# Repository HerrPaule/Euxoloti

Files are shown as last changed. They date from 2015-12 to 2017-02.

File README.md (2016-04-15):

# Euxoloti
Euxoloti is a project to use the great Axoloti core in the world of Eurorack. 

The project is fully open and released under CC-BY-SA-NC

Further deatils about functions and order, check http://irieelectronics.de/euxoloti
and the Axoloti Forum: http://community.axoloti.com/t/euxoloti-for-axoloti-eurorack-module/

A great detailed build step by step instruction by FMA from the Axoloti Forum (work in progress): https://docs.google.com/document/d/1Rx9O_k-dUJQDzONVk0AzewmyFckbQyXHiNsPy8fmUj8/edit

AXOLOTI: http://axoloti.be
<br>
Book about the Axoloti: https://leanpub.com/getting-started-with-axoloti

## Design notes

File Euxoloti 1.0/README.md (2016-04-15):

##### Changelog

####### Core PCB Version 1.1:
- error correction 
- some components are rearranged or deleted
- Analog ground for ADCs, POTs and AUDIO
- better heat management for Vreg (PCB can be used as heat sink or a heatsink for TO-220)
- CS pins from ADCs are connected to other Axo pinouts
- detailed labels for pin outs and used pins.
- connections to connect upcoming "GAT8" and "USB2MCV" extensions. 
- optional use of lin/rin pins for audio directly or normalize the Eurorack signal by a big audio jack to the audio input header behind Axo's audio in jack. so you can use mics etc. like normal with Axoloti) 

####### Control PCB Version 1.1:
- larger PCB height to connect the bottom Thonkiconn jack row directly to the PCB
- single ground pins (AGND/DGND) for CV IN/GATE, POT, AUDIO I/O and pushbutton/led GND
- footprint is for LP4OA1PBCTG or D6 switches
- LEDs are now connected to PWM outputs
- Pot orientation is compatible to d-shaft type pots

####### New:
PCB Panels for Control, GAT8 and USB2MCV

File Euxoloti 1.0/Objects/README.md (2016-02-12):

### Euxoloti Objects
- LED + Button Object: It reads the pushbutton states and let you turn on/off the LEDs. 
- Gate Object: It's reads and outputs the value of the gate cv in jacks. (Only on/off)

###Installation:
1. go to axoloti's object folder Mac: ./Applications/Axoloti.app/Contents/Java/objects/
2. create a new dir and name it "euxoloti"
3. copy the "button-led.axo" & "gate.axo"
4. start axaloti app and it will update its object list (no error at axoloti console)
5. the editor should list now euxoloti

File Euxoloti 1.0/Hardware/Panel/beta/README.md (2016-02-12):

The actually used panel is a printed [3mm Alu-Dibond plate](https://de.whitewall.com/fotolabor/alu-dibond/direktdruck-aluminium?linkId=TopNavigation) comes from white wall.
- Width: 101mm
- Height: 128mm

Drill positions are marked by Crosses.

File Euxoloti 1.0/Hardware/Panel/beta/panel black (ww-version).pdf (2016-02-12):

GATE IN | AUDIO
OUT R | OUT L

CV IN

1 | 2 | 3 | 4
5 | 6 | 7 | 8

1

2

IN R | IN L
1 | 2 | 3 | 4
P1 | P2 | P3 | P4
P5 | P6 | P7 | P8
BUTTON
- | + - | + - | + - | +
- | + - | + - | + - | +

## EUXOLOTI

### irie electronics

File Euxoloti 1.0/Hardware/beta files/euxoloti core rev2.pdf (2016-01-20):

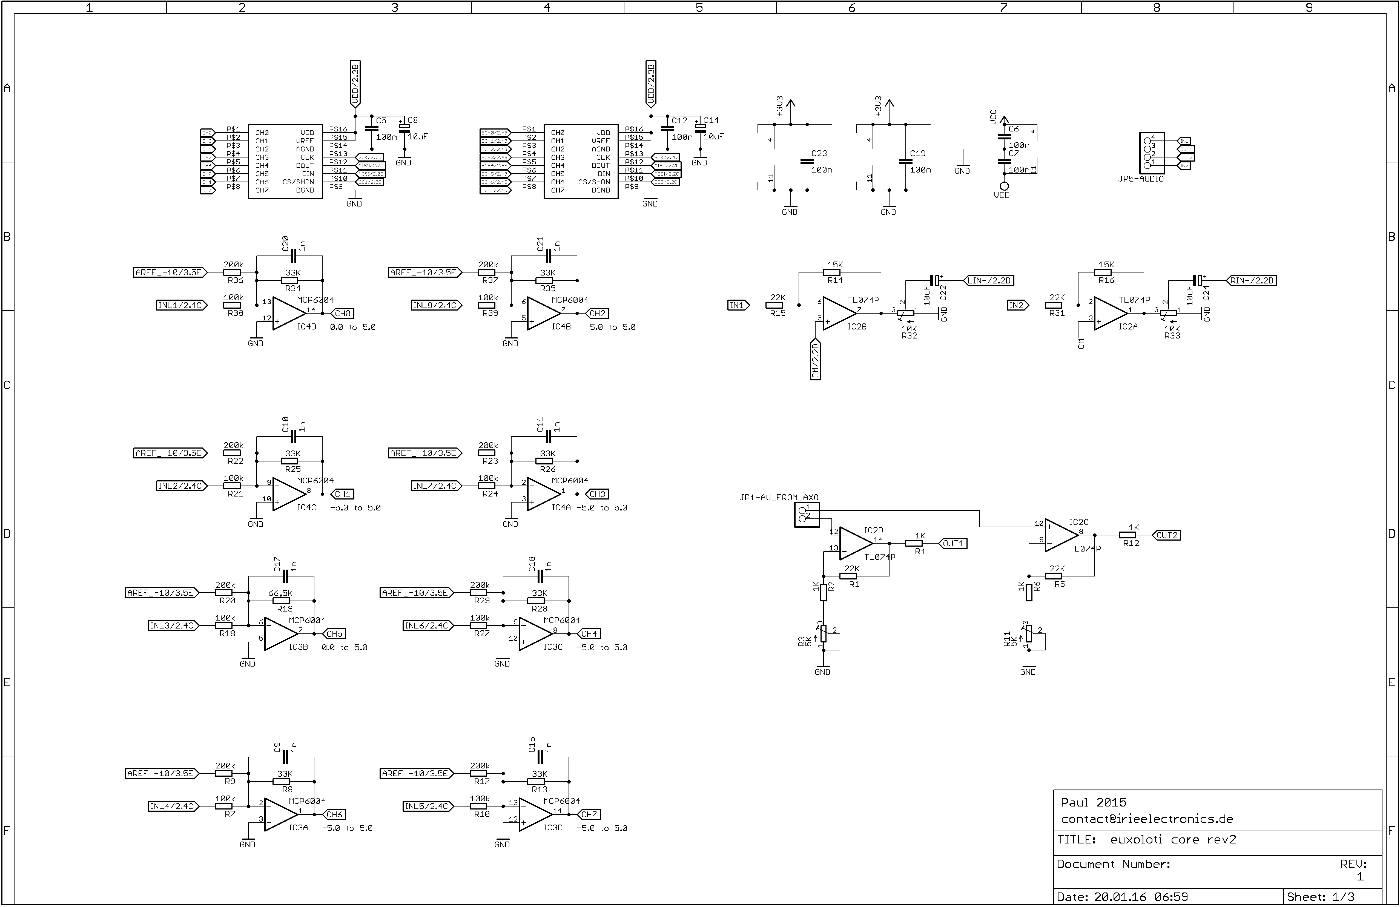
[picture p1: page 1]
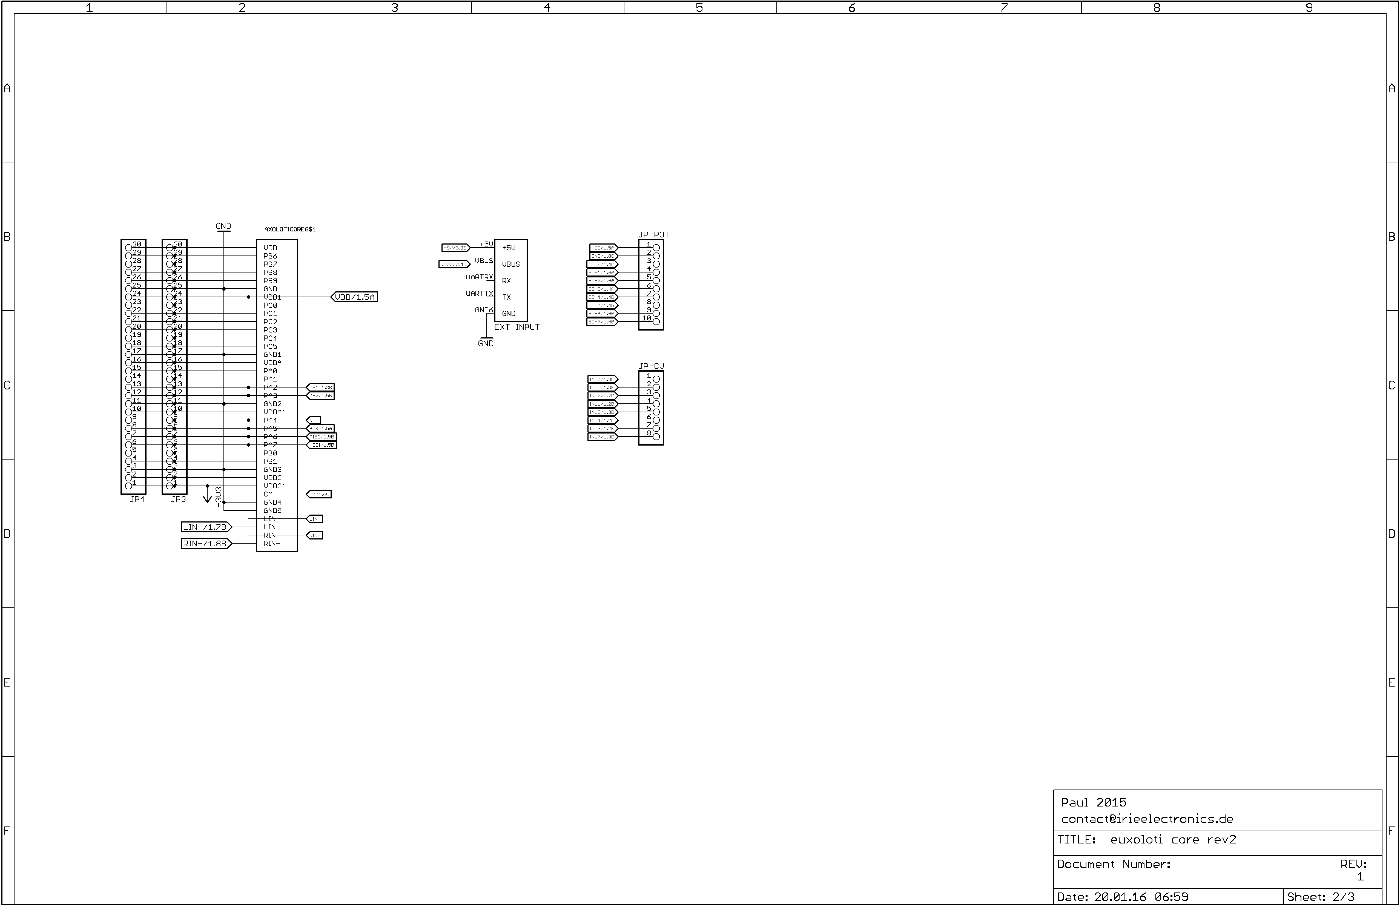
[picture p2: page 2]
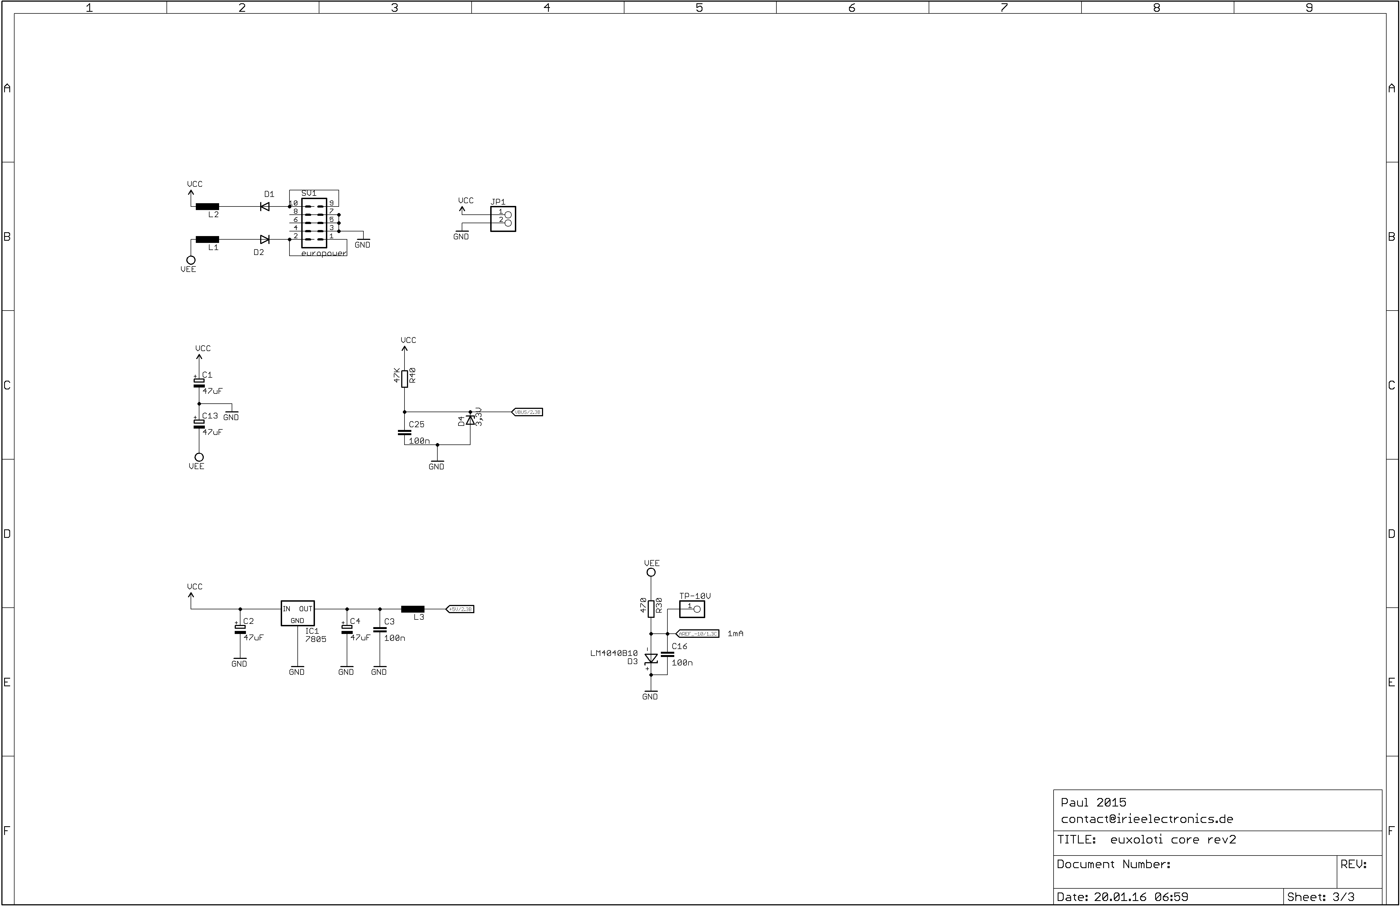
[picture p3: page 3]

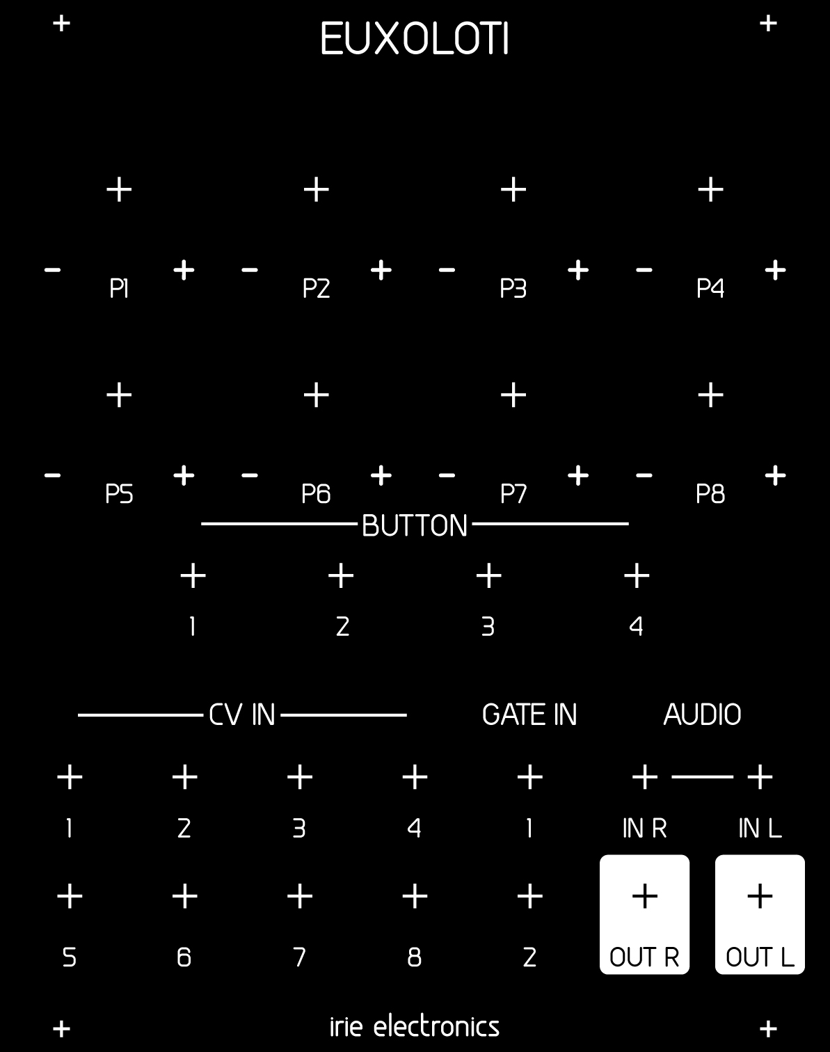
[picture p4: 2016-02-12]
Euxoloti 1.0/Hardware/Panel/beta/panel black (ww-version).jpg

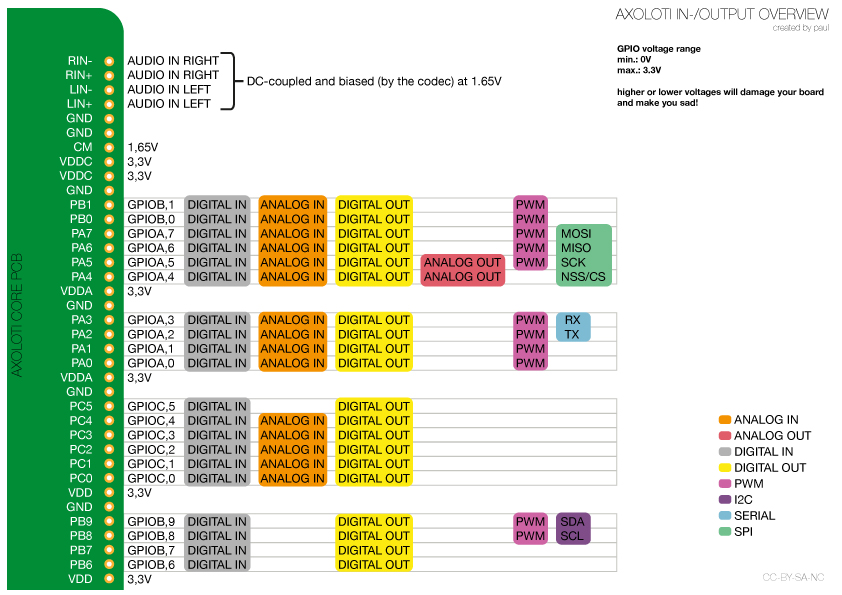
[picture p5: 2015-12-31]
AXOLOTI PINOUT OVERVIEW/axoloti-gpio-io-v2.jpg

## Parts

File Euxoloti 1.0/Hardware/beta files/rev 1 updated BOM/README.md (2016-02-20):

## Please, also add following parts to your shopping cart:
- Axoloti Pinout: 1x37 pin male header row
- Axoloti Power: 1x5 pin male header row
- Axo-Euxo Connection: 36pin female header row  
- Axo-Euxo Power: 1x5 pin female header row 

#### Mouser carts:
- [BOM Core PCB](http://www.mouser.com/ProjectManager/ProjectDetail.aspx?AccessID=0fd288abd9)
- [BOM Control PCB](http://www.mouser.com/ProjectManager/ProjectDetail.aspx?AccessID=da0791eec8)
- [Axo-Euxo Header](http://www.mouser.com/ProjectManager/ProjectDetail.aspx?AccessID=f23408b07c)

#### special note about pots
toneburst@axoloti forum (euxoloti thread):
Also, just noticed the pots are in different orientations, which means I can't use the Panasonic pots, or the pointers on the knobs will point in the wrong directions.

Might have been a good idea to make a note of that in the BOM or, preferably put all the pots the same way round, so people can use D-Shaft pots if they want to. It's not a dense board, wouldn't be difficult to orient them all like the top row, I don't think.

from: http://community.axoloti.com/t/euxoloti-for-axoloti-eurorack-module/100/102?u=paul

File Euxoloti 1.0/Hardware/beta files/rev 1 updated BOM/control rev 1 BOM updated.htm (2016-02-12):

Euxoloti Control PCB REV 1.0 updated BOM
Qty | Parts | Value | Description | Package | Mouser | Alternative
4 | R1, R3, R5, R7 | 68R | Resistor, 5% |  | 71-CCF0768R0JKE36
2 | R11, R12 | 10K | Resistor, 5% |  | 660-MF1/4LCT52R103J
2 | R9, R10 | 100K | Resistor, 5% |  | 660-MF1/4LCT52R104J
2 | T1, T2 | 2N3904 | NPN Transistor | TO-92 | 512-2N3904TAR
4 | B1, B2, B3, B4 | Switch, On-mom, Green LED |  |  | 612-LP4OA1PBCTG | 612-LP4OA1PBCTR
1 | JP-POT | 1x10 male header, 2.54mm pitch | check core bom | 1X10
1 | JP1 | 1x30 male header, 2.54mm pitch | check core bom | 1X30
1 | JP3-AUDIO | 1x4 male header, 2.54mm pitch | check core bom | 1X04
1 | JP3-CV | 1x8 male header, 2.54mm pitch | check core bom | 1X08
8 | POT1, POT2, POT3, POT4, POT5, POT6, POT7, POT8 | 10K | Alpha, 10k linear pot, vertical | 9mm |  | https://www.thonk.co.uk/shop/alpha-9mm-pots/
14 | A-IN1, A-IN2, A-OUT1, A-OUT2, CV1, CV2, CV3, CV4, CV5, CV6, CV7, CV8, G-IN1, G-IN2 | THONKICONN |  |  |  | https://www.thonk.co.uk/shop/3-5mm-jacks/
1 |  | M3, 10mm | Spacer female | 10mm | 855-R30-1001002
1 |  | M3, 6mm | Screw | 6mm | 534-9191-4

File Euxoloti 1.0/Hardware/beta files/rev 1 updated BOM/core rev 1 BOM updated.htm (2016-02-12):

Euxoloti Core PCB REV 1.0 updated BOM
Qty | Parts | Value | Description | specs | Package | Mouser
3 | L1, L2, L3 |  | Ferrite Bead |  |  | 81-BL01RN1A1D2B
1 | R30 | 470R |  |  |  | 660-MF1/4DC4700F
4 | R2, R4, R6, R12 | 1K | Resistor, 1% |  |  | 660-MS1/4DCT52R1001
2 | R14, R16 | 15K | Resistor, 1% |  |  | 660-MFS1/4DCT52R1502
4 | R1, R5, R15, R31 | 22K | Resistor, 1% |  |  | 660-MF1/4DC2202F
7 | R8, R13, R25, R26, R28, R34, R35 | 33K | Resistor, 1% |  |  | 660-MF1/4DC3302F
1 | R40 | 47K | Resistor, 1% |  |  | 660-MF1/4LCT52R473J
1 | R19 | 66,5K | Resistor, 1% |  |  | 660-MF1/4DC6652F
8 | R7, R10, R18, R21, R24, R27, R38, R39 | 100k | Resistor, 1% |  |  | 660-MF1/4D52R1003F
8 | R9, R17, R20, R22, R23, R29, R36, R37 | 200k | Resistor, 1% |  |  | 660-MF1/4DC2003F
2 | R3, R11 | 5K | Trimmer |  |  | 652-3299P-1-502LF
2 | R32, R33 | 10K | Trimmer |  |  | 652-3299P-1-103LF
8 | C9, C10, C11, C15, C17, C18, C20, C21 | 1n | Capacitor, ceramic | >= 16V, <= 2% | Pitch: 5mm | 80-C322C102F5G
9 | C3, C5, C6, C7, C12, C16, C19, C23, C25 | 100n | Capacitor, ceramic | >= 16V | Pitch: 2,5mm | 75-1C10Z5U104M050B
4 | C8, C14, C22, C24 | 10uF | Capacitor, electrolytic | >= 6V | Pitch: 1,8mm; Dia.: 4mm | 667-ECE-A1CKS100
4 | C1, C2, C4, C13 | 47uF | Capacitor, electrolytic | >= 16V | Pitch: 2mm; Dia.: 5mm | 667-ECE-A1CKA470
2 | D1, D2 | 1N5819 | Diode |  | DO35 | 512-1N5819
1 | D4 | 3,3V, 500mW | Zener Diode |  | DO35 | 771-BZX79-C3V3-T/R
1 | D3 | LM4040 10V | Ref Diode | A, B or C grade | TO-92 | 926-LM4040AIZ100NOPB
1 | IC1 | 7805 | Voltage Regulator |  | TO-220 | 512-LM7805ACT
2 | IC5, IC6 | MCP3208 | ADC |  | DIL16 | 579-MCP3208CIP
2 | IC3, IC4 | MCP6004 | OP AMP |  | DIL14 | 579-MCP6004-I/P
1 | IC2 | TL074 | OP AMP |  | DIL14 | 595-TL074CN
1 | JP_POT |  | 1x10 female header, 2.54mm pitch |  | 1X10
2 | JP3, JP4 |  | 1x30 female header, 2.54mm pitch |  | 1X30
1 | JP5-AUDIO |  | 1x4 female header, 2.54mm pitch |  | 1X04
1 | JP-CV |  | 1x8 female header, 2.54mm pitch |  | 1X08
1 | SV1 |  | 2x10 male header, 2.54mm pitch |  | 2x10
 |  |  | IC Socket, DIL14 |  |  | 649-DILB14P-223TLF
3 |  |  | IC Socket, DIL16 |  |  | 649-DILB16P-223TLF
2
1 |  | M3, 10mm | Spacer female/male |  | 10mm | 855-R30-3001002
1 |  | M3, 6mm | Screw |  | 6mm | 534-9191-4
2 |  | 10cm | Cable to connect axoloti audio out
1 |  |  | 1x2 femal crimp contact |  | 1x2
1 | AXOLOTICORE | AXOLOTI CORE |  |  |  |  | http://www.axoloti.com/product/axoloti-core/
1 | Eurorack power cable
 | HINT:
2 |  |  | only for core | (cut to fit) | 1x36 female header, 2.54mm pitch |  |  | 517-929974-01-36-RK
2 |  |  | core & control pcb | (cut to fit) | 1x36 male header, 2.54mm pitch |  |  | 649-68000-436HLF

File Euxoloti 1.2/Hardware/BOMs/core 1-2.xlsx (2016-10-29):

Qty | Value | Parts | Description | Package | DIGI Key | MOUSER
3 |  | L1, L2, L3 | EMI Filter Bead |  | 490-10997-ND | 623-2743002112LF
1 | 470R | R39 | Resistor, 1% |  | RNF14FTD470RCT-ND
2 | 1K | R19, R20 | Resistor, 1%
4 | 3,3K | R13, R14, R35, R36 | Resistor, 1%
2 | 10K | R41, R42 | Resistor, 1%
4 | 22K | R17, R18, R29, R30 | Resistor, 1%
7 | 33K | R3, R4, R11, R12, R24, R33, R34 | Resistor, 1%
1 | 66,5K | R23 | Resistor, 1%
9 | 100k | R1, R2, R9, R10, R21, R22, R31, R32, R40 | Resistor, 1%
8 | 200k | R5, R6, R15, R16, R25, R26, R37, R38 | Resistor, 1%
1 | 10K | RN1 | Resistor Networks, Star Connection | 4x10k (5legs)
2 | 5k | R7, R8 | Trimmers Pots, Precision, horizontal, triangle legs |  |  | 652-3296P-1-502LF
2 | 10K | R27, R28 | Trimmers Pots, Precision, horizontal, triangle legs |  |  | 652-3296P-1-103LF
8 | 1n | C1, C2, C3, C4, C5, C6, C9, C10 | Capacitor, film; <=2.5% | pitch: 2,5mm or 5mm |  | 505-FKP21000/100/2.5
8 | 100n | C11, C12, C13, C14, C17, C20, C21, C22 | Capacitor, ceramic | pitch: 2,5 | 445-5312-ND
1 | 330n | C15 | Capacitor, ceramic | pitch: 2,5
2 | 10uF | C7, C8 | Capacitor, electrolytic | pitch: 1,8mm; Dia 4mm
2 | 47uF | C18, C19 | Capacitor, electrolytic | pitch: 2mm; Dia: 5mm | 493-11510-1-ND
4 | 1N4001 | D2, D4, D5, D6 | Diode | DO35
1 | 3,3V | D3 | Zener diode | DO35
1 | LM4040A10 | D1 | LM4040 Shunt Vref; A, B or C grade | TO-92 | LM4040AIZ-10.0/NOPB-ND | 926-LM4040AIZ100NOPB
1 | 7805 | VREG | Vreg | TO-220 | LM7805ACT-ND | LM7805ACT
2 | MCP6004 | IC1, IC3 | Op amp | DIL14 | MCP6004-I/P-ND
1 | TL074P | IC2 | Op amp | DIL14
1 | MAPPLE_MINI_REV2 | IC4 | Maple Mini Clone | STM32F103RCBT6 | http://www.ebay.de/itm/Mini-USB-STM32F103RCBT6-ARM-Cortex-M3-leaflabs-Leaf-Maple-Mini-Module-F-Arduino-/182198487350
1 | Axoloti Core | Axoloti Core |  |  | http://www.axoloti.com/
2 | female | Maple Mini (IC4) | PIN HEADER | 1X20; pitch: 2,54mm; low profile
1 | female | JP-MM | PIN HEADER | 1X20; pitch: 2,54mm | 929850E-01-20-ND
1 | female | JP-AG | PIN HEADER | 1X7; pitch: 2,54mm | 929974E-01-36-ND
1 | female | JP-MGVG | PIN HEADER | 2X5; pitch: 2,54mm | to use some 1x36 is cheaper
1 | female | JP-BLCG | PIN HEADER | 2X11; pitch: 2,54mm | to use some 1x36 is cheaper
1 | female | AXO_CORE | PIN HEADER | 1x37; pitch: 2,54mm | to use some 1x36 is cheaper
1 | female | AXO_CORE (Power, MIDI Section) | PIN HEADER | 1x5; pitch: 2,54mm | to use some 1x36 is cheaper
1 | male | EURORACK-POWER | PIN HEADER | 2X5; pitch: 2,54mm
3 |  | IC Socket |  | DIL14
1 | fe-/male | Nylon Stand off |  | 10mm; M3 | 36-25501-ND
1 | female | Nylon Stand off |  | 10mm; M3 | 36-25510-ND
1 |  | Heatsink |  | TO-220 | HS115-ND
1 |  | Thermal pad |  | TO-220 | BER167-ND
85
For Axoloti Core
1 | male | AXO_CORE |  | 1x37
1 | male | AXO_CORE (Power, MIDI Section) |  | 1x5
red marked parts not included in part kits!

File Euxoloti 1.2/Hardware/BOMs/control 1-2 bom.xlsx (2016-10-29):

Qty | Value | Parts | Description | Package | DIGI Key | MOUSER
2 | 51R | R7, R8 | Resistor, 1%
4 | 68R | R1, R2, R13, R19 | Resistor, 1%
1 | 220R | R10 | Resistor, 5%
5 | 10K | R4, R6, R11, R14, R20 | Resistor, 1%
4 | 100K | R3, R5, R9, R12 | Resistor, 1%
1 | 100n | C1 | Capacitor, ceramic | pitch: 2,5mm
1 | 1N4148 | D1 | Diode | DO35
4 | 2N3904 | N1, N2, N3, N4 | NPN Transistor | TO92
1 | 6N137 | IC2 | Opto coupler | DIL08
16 | THONKICONN | A-IN1, A-IN2, A-OUT1, A-OUT2, CV1, CV2, CV3, CV4, CV5, CV6, CV7, CV8, G-IN1, G-IN2, G-IN3, G-IN4 | 3.5mm socket for Eurorack modular synths |  | https://www.thonk.co.uk/shop/3-5mm-jacks/
1 | USB-LUMBERG | USB-B_JACK |  | USB-B
2 | MIDIJACK | MIDIIN, MIDIOUT |  | SD-50BV | CP-3150-ND
1 | male | USB-AXO | pitch 2,54mm | 1x5 | WM4203-ND
1 | female |  | pitch 2,54mm | 1x5 | WM2003-ND
5 |  | crimp |  | female header, crimp contact | WM1114-ND
8 | 10K, linear | POT1, POT2, POT3, POT4, POT5, POT6, POT7, POT8 | 9mm vertical snap-in pot, Alpha / Panasonic style
4 | LP4OA1PBCTG | B1, B2, B3, B4 |  | LP4OA1PBCT | EG4650-ND | 612-LP4OA1PBCTR
1 | male | JP-MM1.1 | PIN HEADER | 1X03
1 | male | JP-AG | PIN HEADER | 1X07
1 | male | JP-MM1.2 | PIN HEADER | 1X09
1 | male | JP-BLC | PIN HEADER | 2X11
1 | male | JP-MGVG | PIN HEADER | 2X05
1 |  |  | 1x5 | 1x5 female header, 2,54mm pitch
1
1 |  |  | USB micro to usb A
1 |  |  | IC Socket | DIL8
70
red marked parts not included in part kits!

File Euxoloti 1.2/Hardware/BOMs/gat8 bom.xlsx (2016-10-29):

Qty | Value | Parts | Description | Device | MOUSER
1 |  | L1 | EMI Filter Bead |  | 623-2743002112LF
8 | 2,2K | R25, R26, R27, R28, R29,R30,R31,R32 | Resistor, 1% | 1206
8 | 4,7K | R5, R6, R7, R8, R9, R10, R11, R12 | Resistor, 1% | 1206
8 | 10K | R1, R2, R3, R4, R21, R22, R23, R24 | Resistor, 1% | 1206
2 | 100nF | C1,C6 | Capacitor, ceramic | 1206
1 | 330n | C3 | Capacitor, ceramic | 1206
1 | 47uF | C2 | Capacitor, electrolytic | pitch: 2mm; Dia: 5mm
1 | 1N4001 | D1 | Diode | 1N4004
8 | 2N3904 | T1, T2, T3, T4, T5, T6, T7, T8 | NPN TRANSISTOR | 2N3904
1 | 78l03 | IC2 | VOLTAGE REGULATOR | TO92
1 | 74LS595N | IC1 | 8-bit SHIFT REGISTER | 74HC595
8 | LED | LED1, LED2, LED3, LED4, LED5, LED6, LED7, LED8 |  | flat LED
1 |  | MASTER | PIN HEADER | PINHD-1X5_2.54
1 | male | EURORACK-POWER | PIN HEADER | 2X5; pitch: 2,54mm
1 | DIP socket |  |  | DIL16
8 | PJ302M | OUT1, OUT2, OUT3, OUT4, OUT5, OUT6, OUT7, OUT8 |  | PJ302M
59
red marked parts not included in part kits!

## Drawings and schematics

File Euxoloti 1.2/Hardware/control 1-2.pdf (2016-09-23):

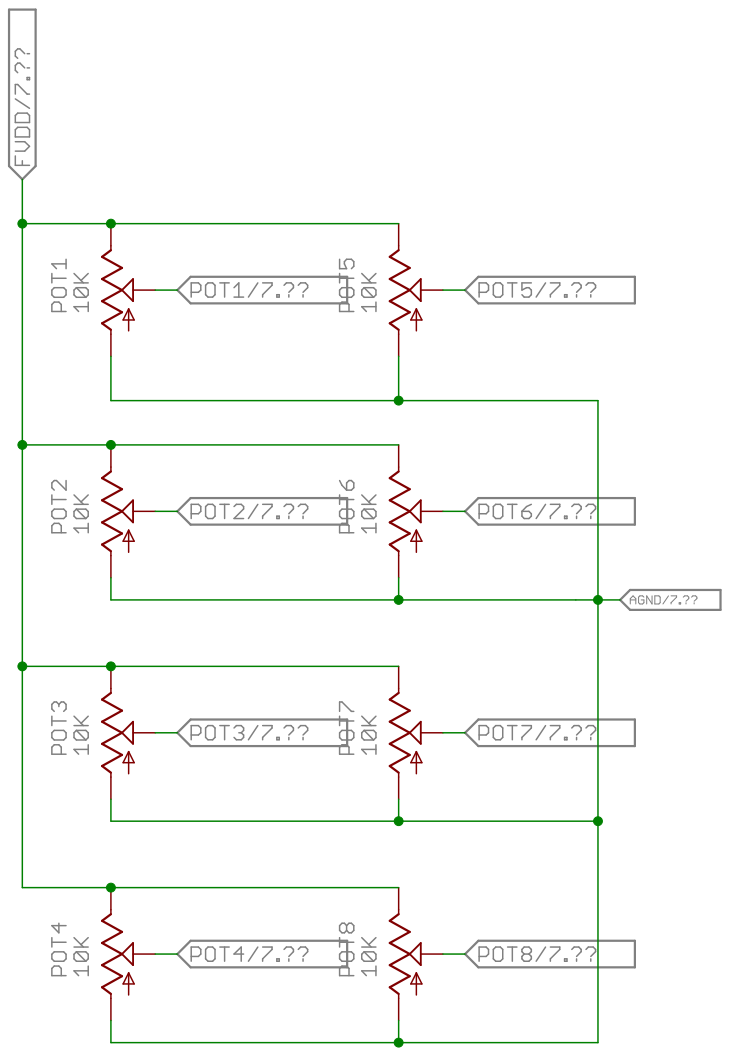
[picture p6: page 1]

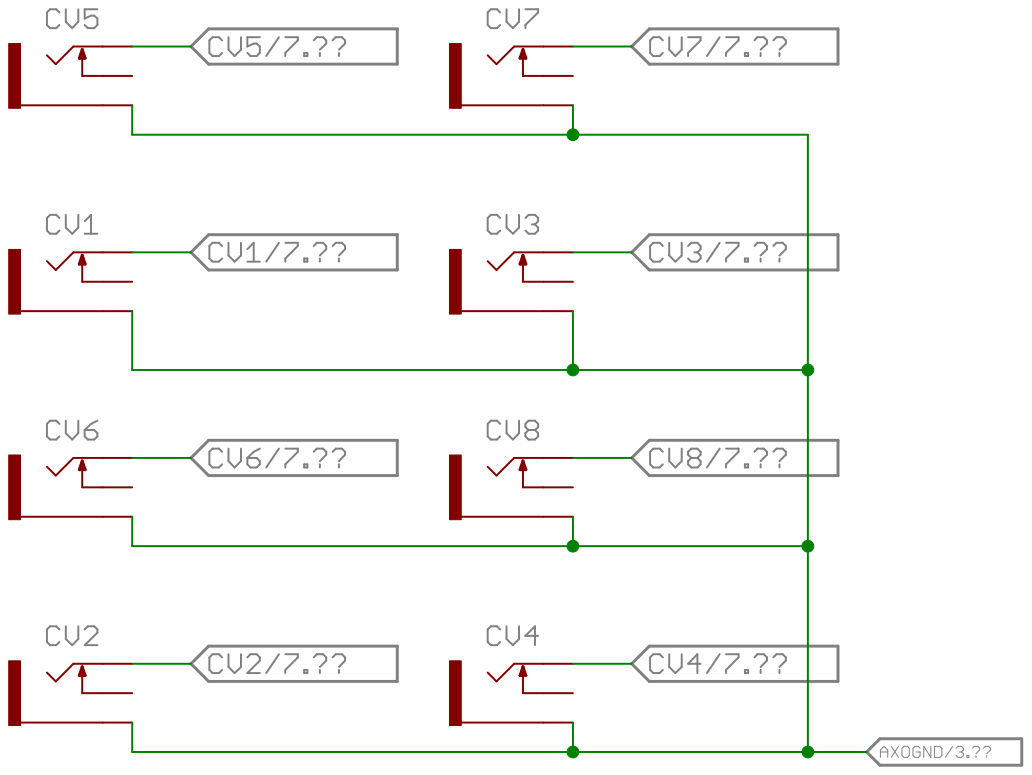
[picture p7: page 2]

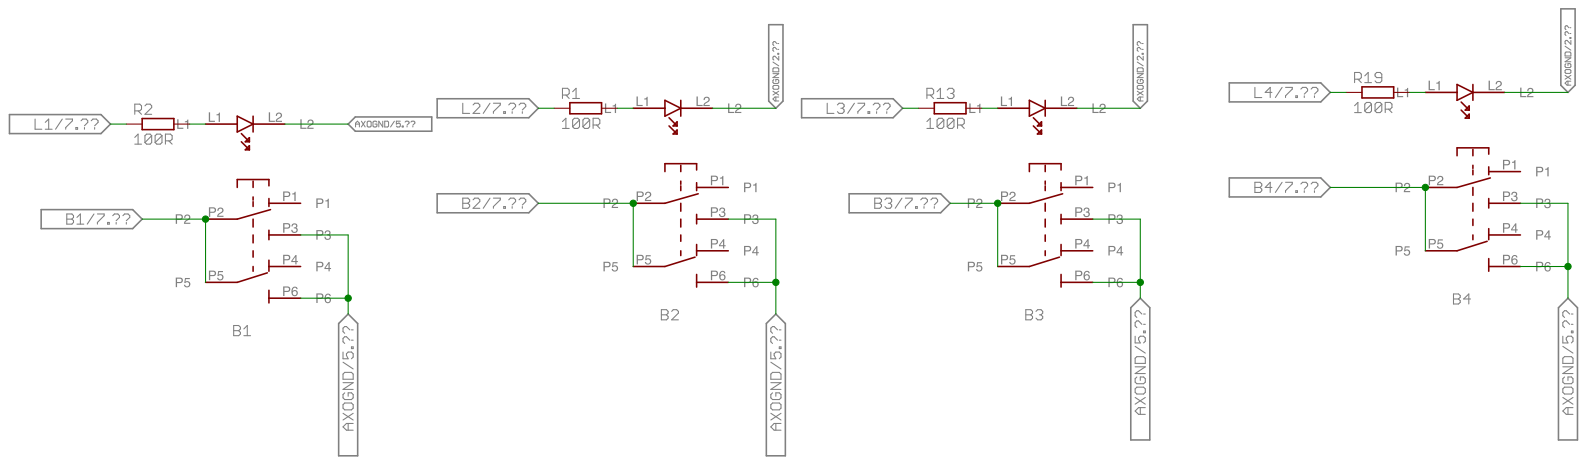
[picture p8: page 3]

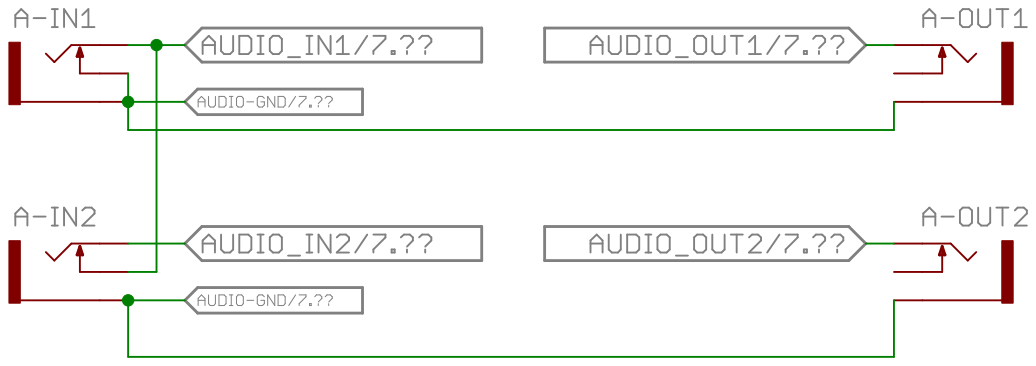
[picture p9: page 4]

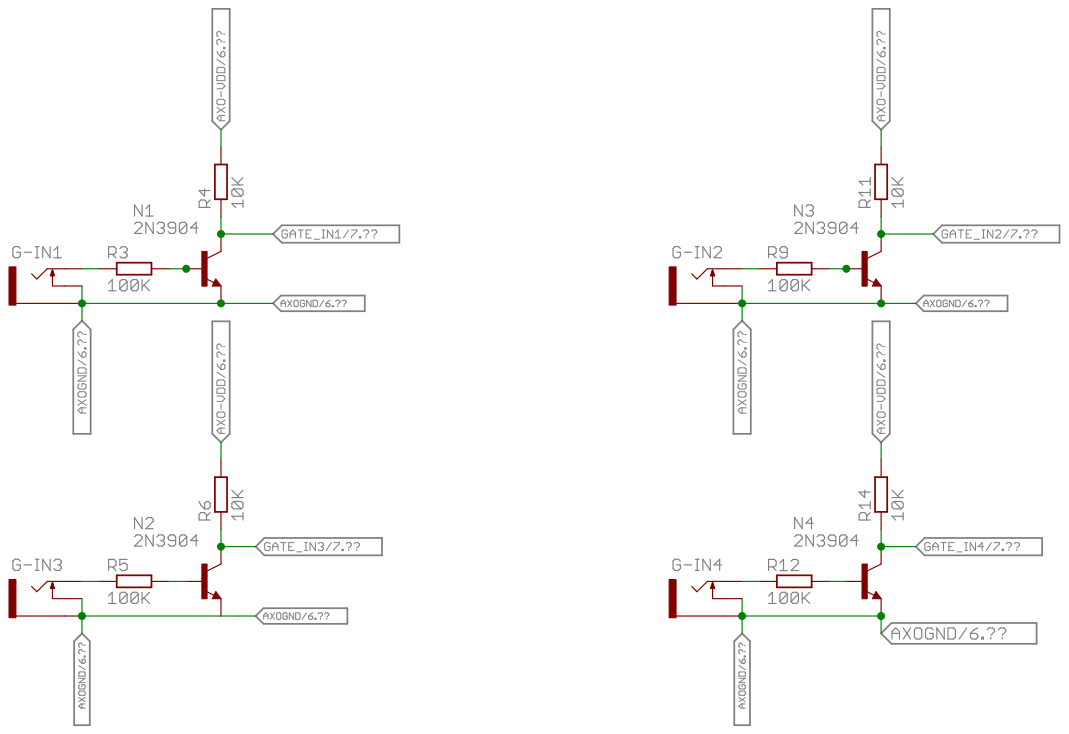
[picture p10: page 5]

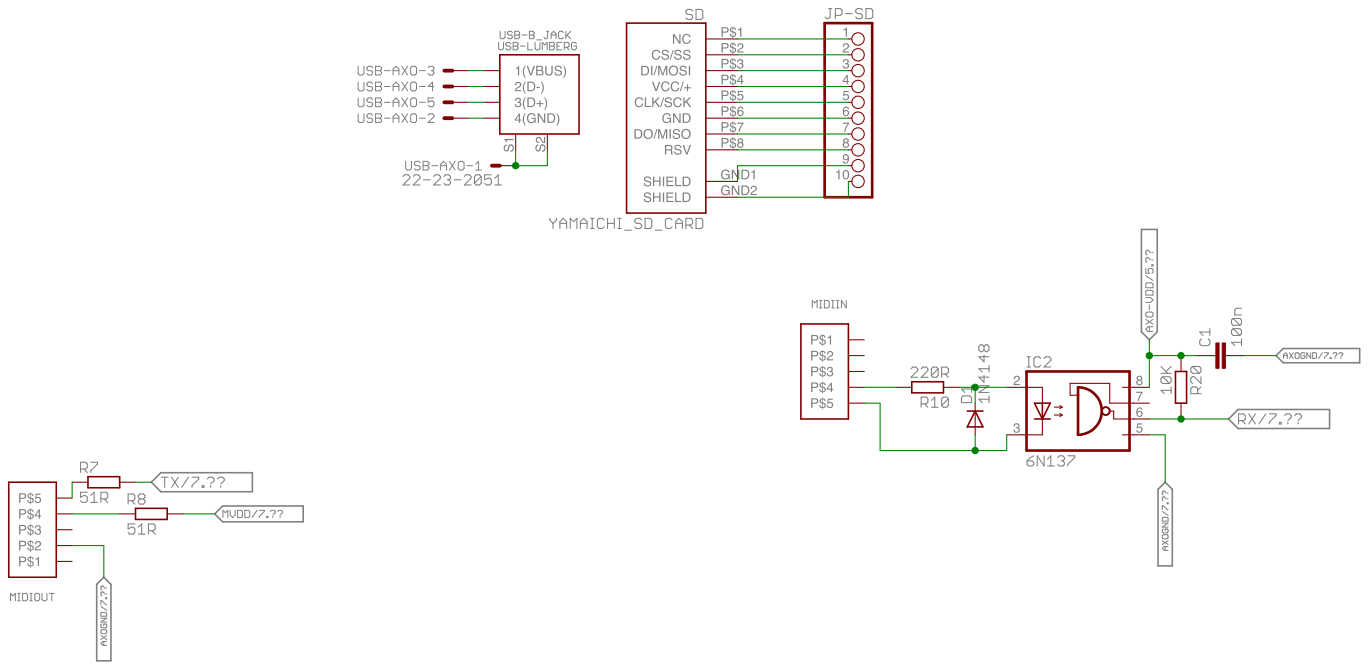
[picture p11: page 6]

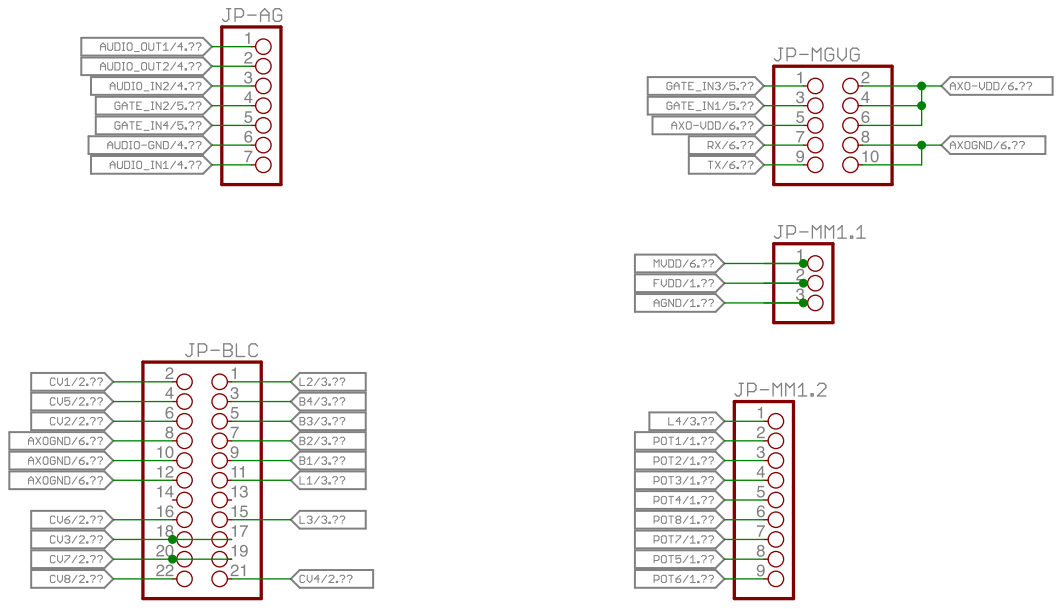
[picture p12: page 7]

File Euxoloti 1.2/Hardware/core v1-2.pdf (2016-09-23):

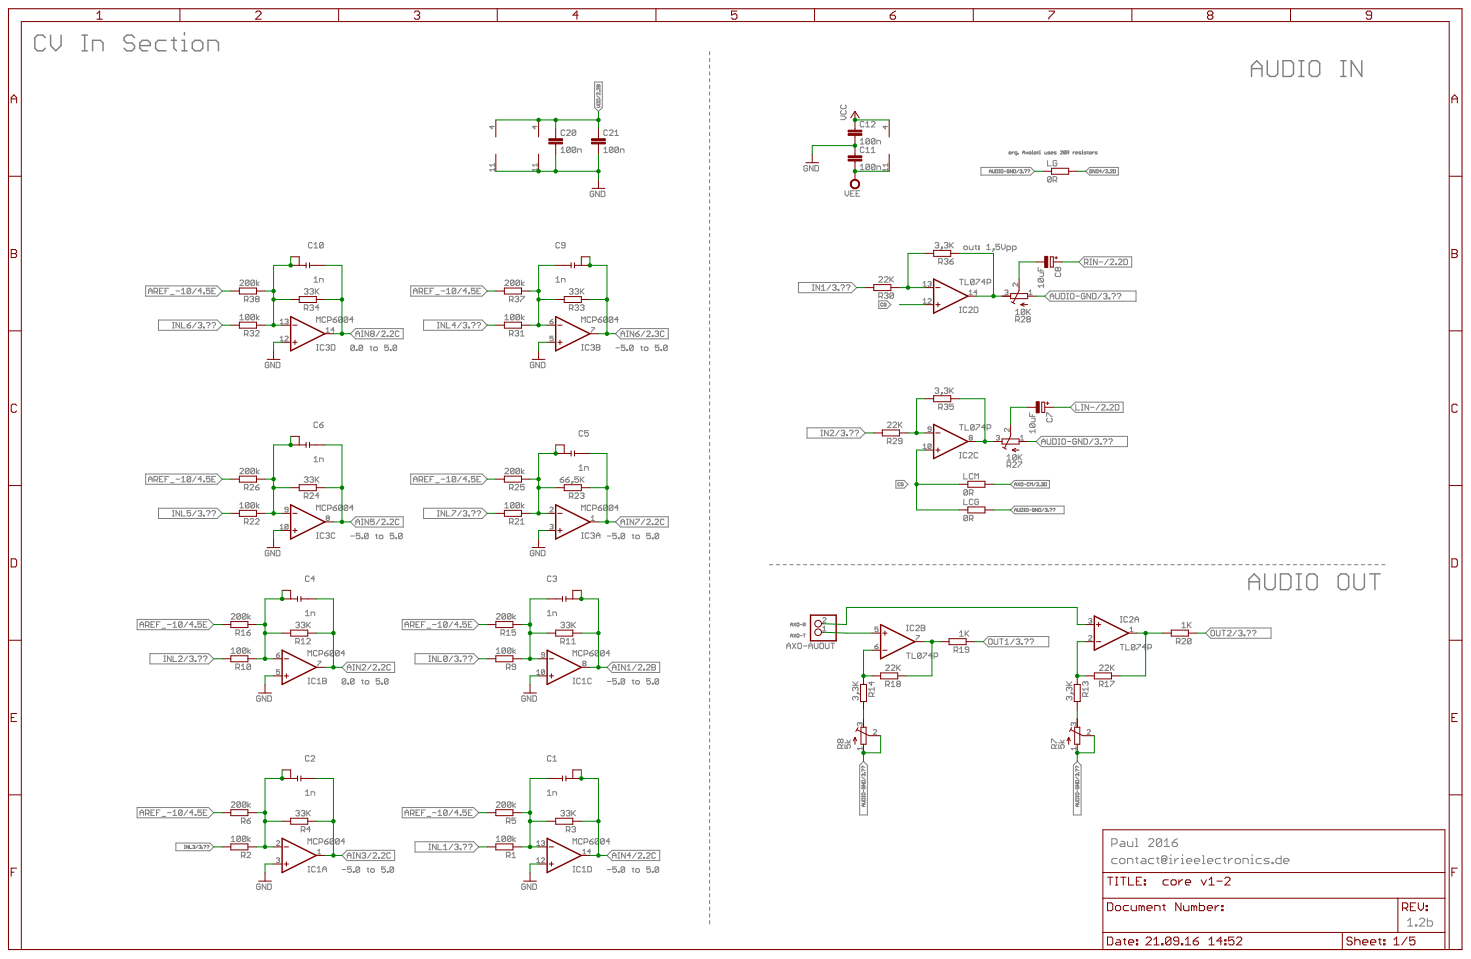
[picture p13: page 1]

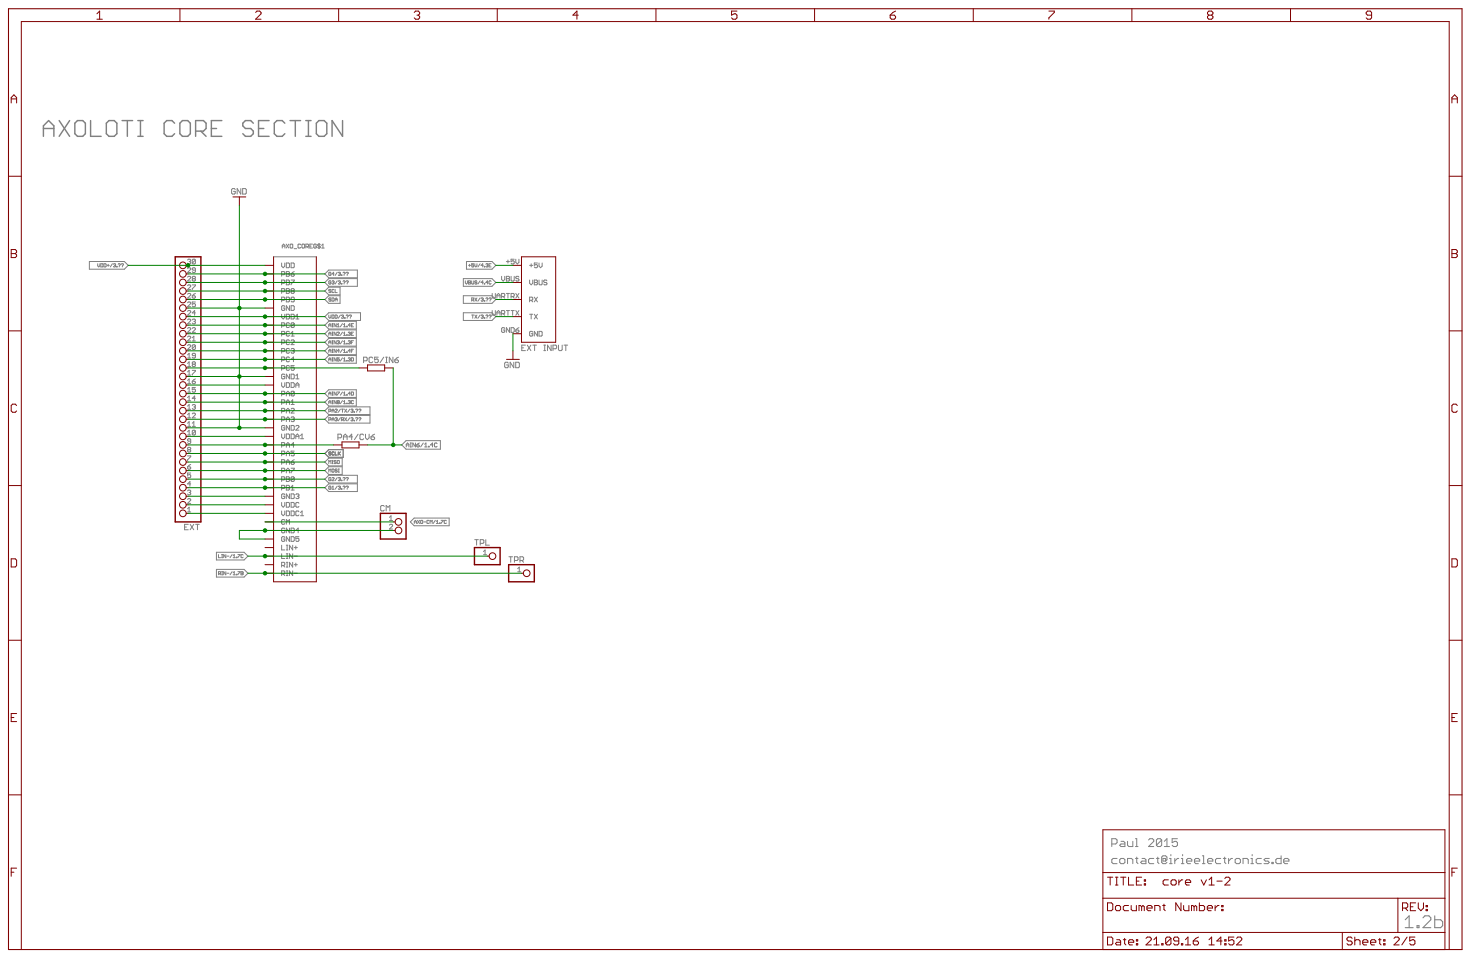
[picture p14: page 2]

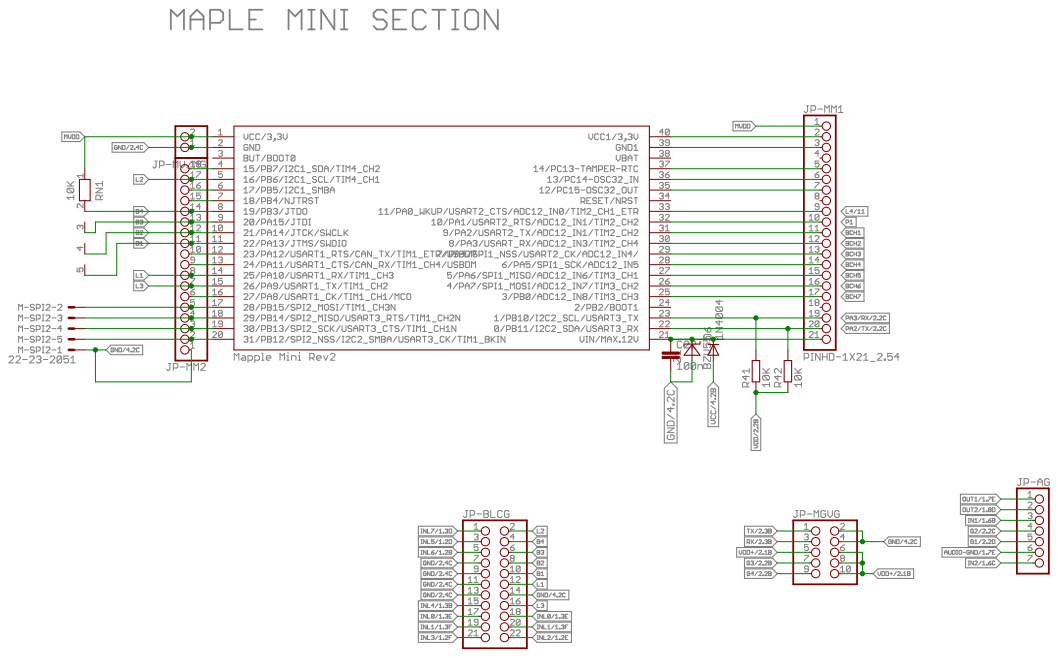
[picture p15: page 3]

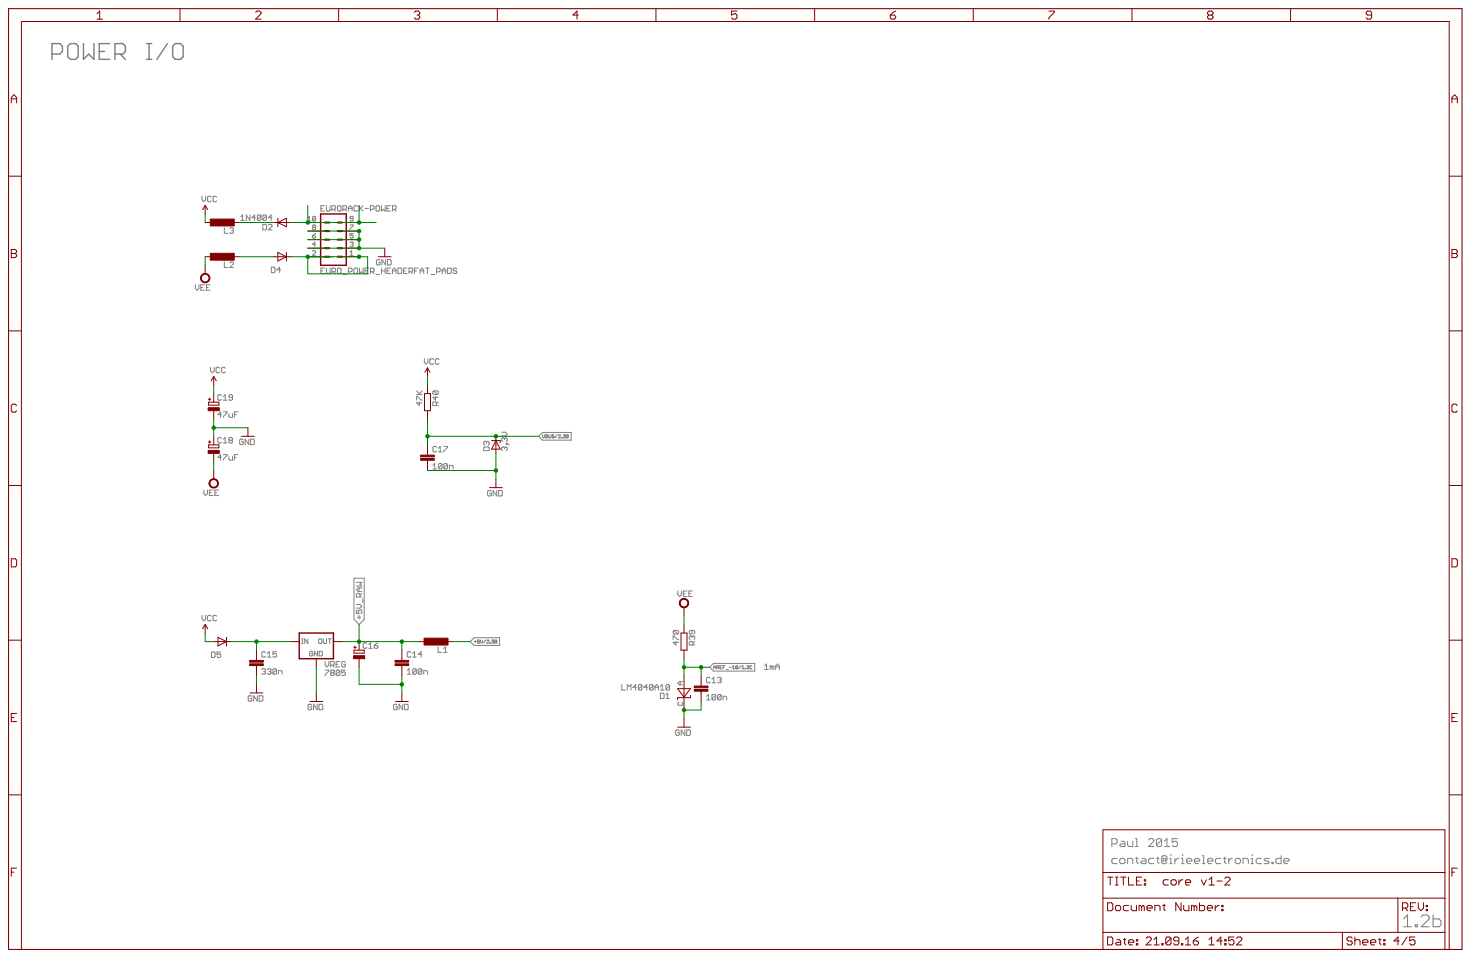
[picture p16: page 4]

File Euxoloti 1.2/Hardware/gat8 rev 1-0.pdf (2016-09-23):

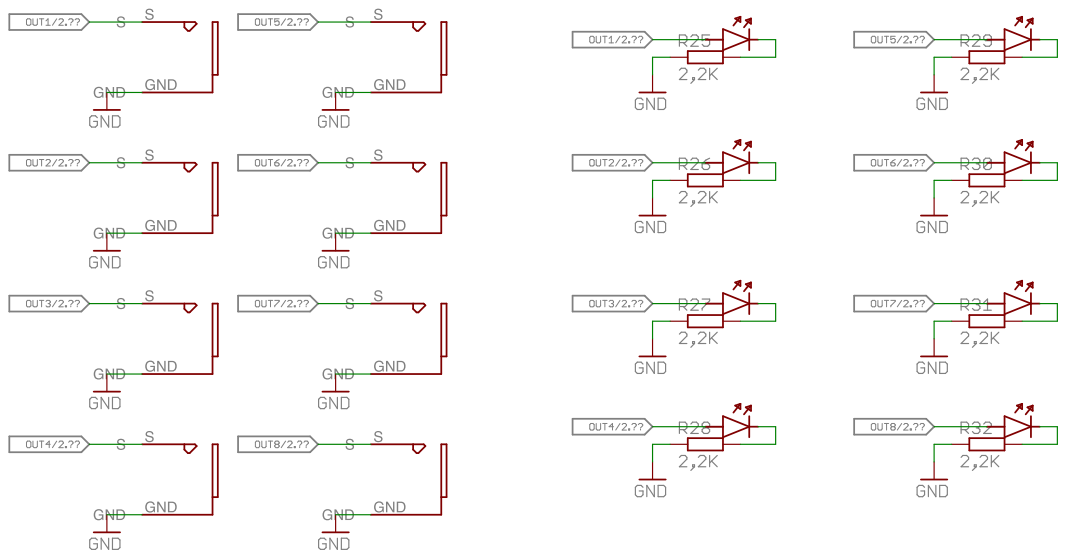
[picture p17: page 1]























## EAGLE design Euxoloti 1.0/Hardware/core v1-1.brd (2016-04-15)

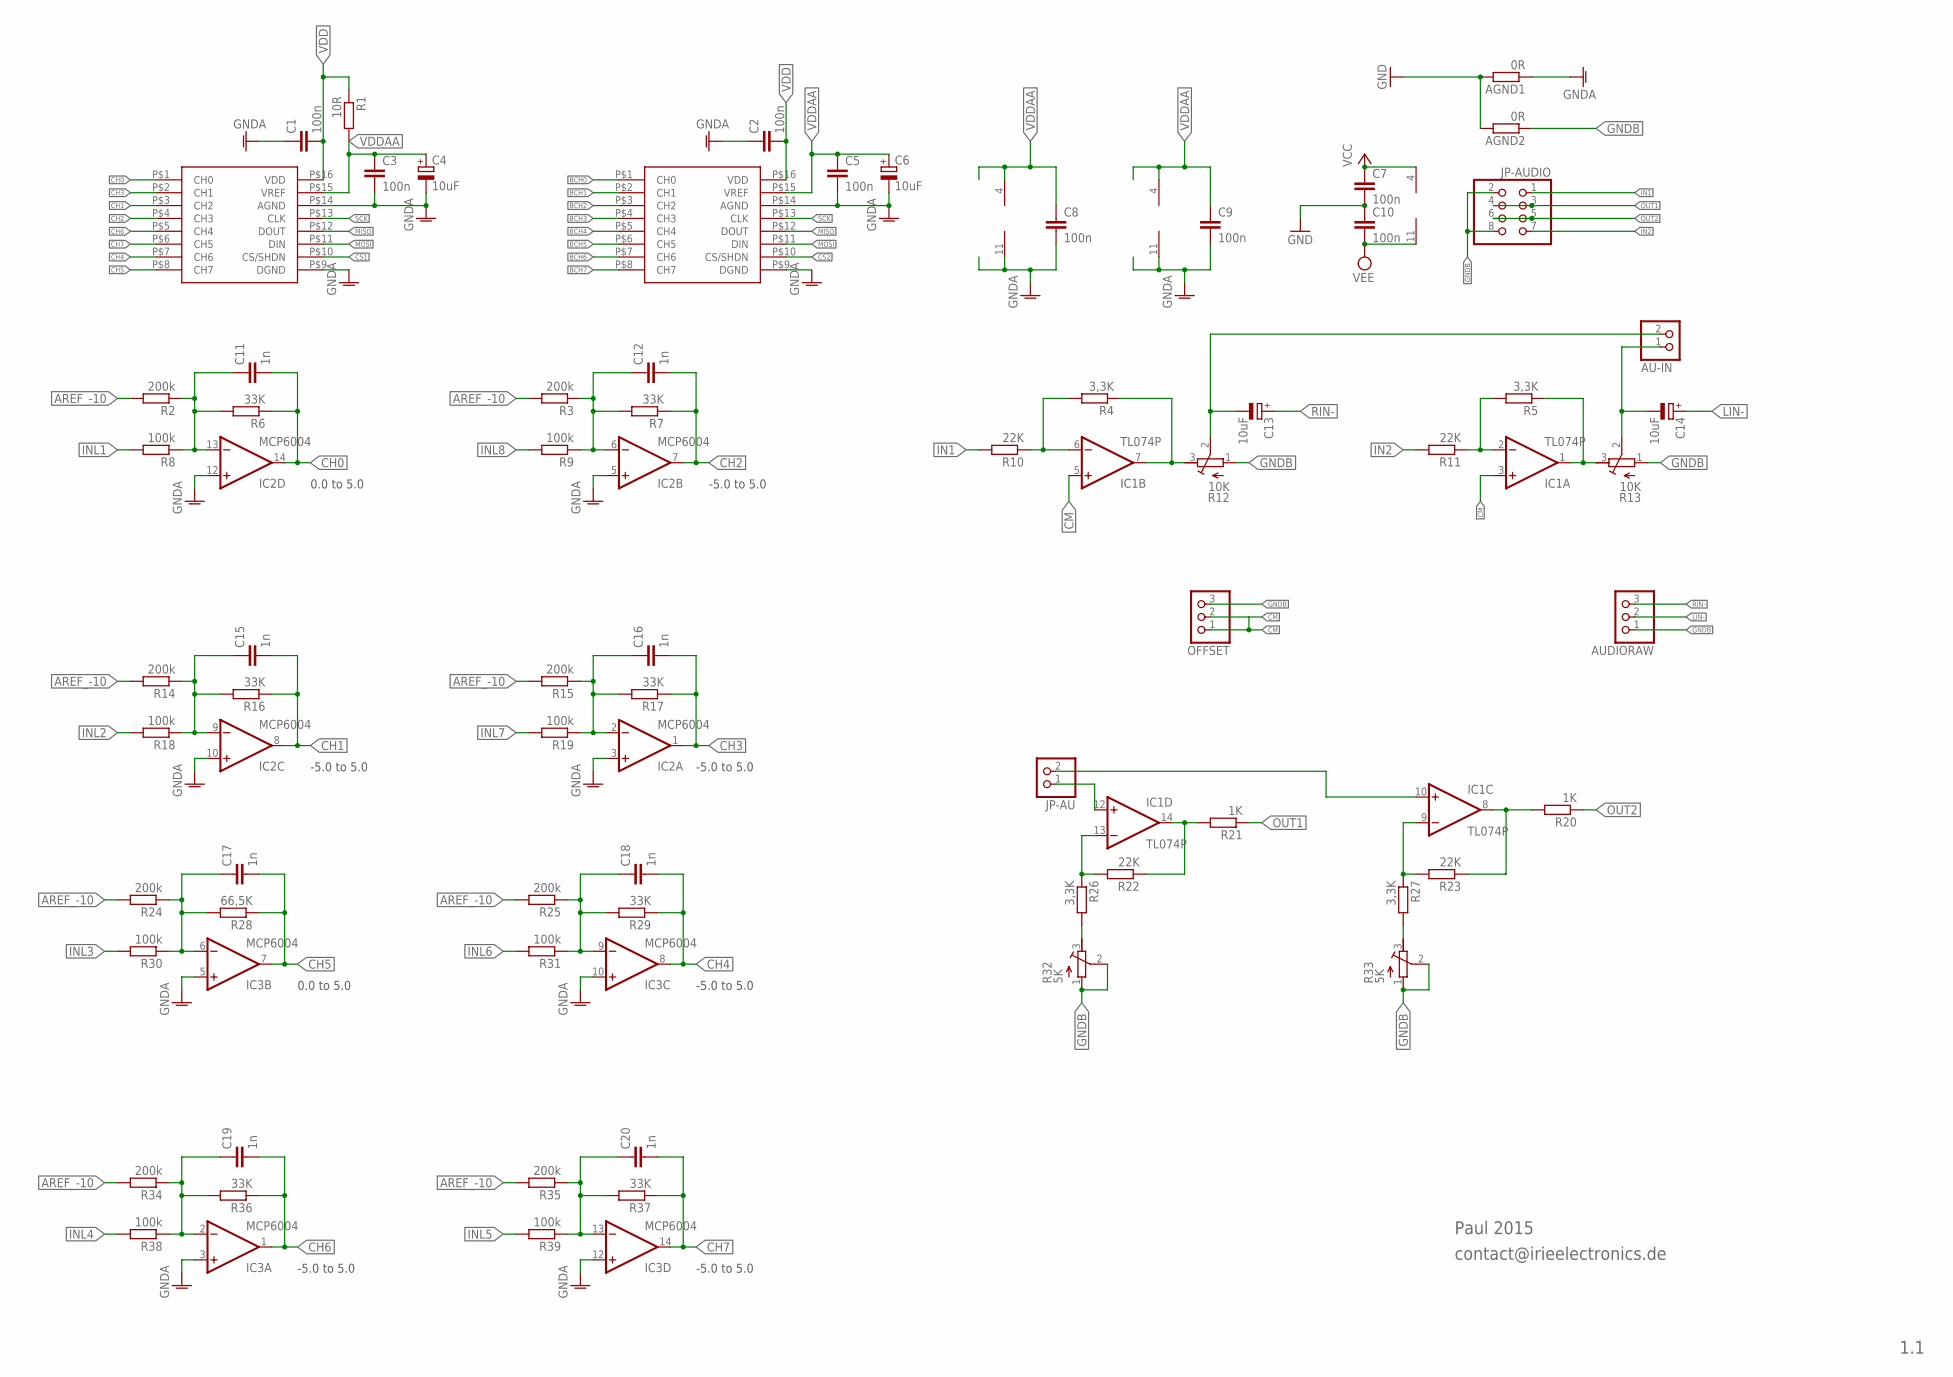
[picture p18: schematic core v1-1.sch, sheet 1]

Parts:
AGND1, AGND2: 0R; 0207/7
AU-IN: PINHD-1X2_2.54-SMD-90°; 1X02SMD/90
AUDIORAW: PINHD-1X3_2.54-SMD-90°; 1X03SMD/90
C1, C2, C3, C5, C7, C8, C9, C10: 100n; C025-025X050
C4, C6, C13, C14: 10uF; E1,8-4
C11, C12, C15, C16, C17, C18, C19, C20: 1n; C050-025X075
IC1: TL074P; DIL14
IC2, IC3: MCP6004; DIL14
JP-AU: PINHD-1X2_2.54; 1X02
JP-AUDIO: PINHD-2X4_2.54; 2X04
OFFSET: PINHD-1X3_2.54-SMD-90°; 1X03SMD/90
R1: 10R; 0207/7
R2, R3, R14, R15, R25, R35: 200k; 0207/7
R4, R5, R27: 3,3K; 0207/7
R6, R7, R16, R17, R29, R36, R37: 33K; 0207/7
R8, R9, R18, R30, R31, R38, R39: 100k; 0207/7
R10, R11, R23: 22K; 0207/7
R12, R13: 10K; RTRIM3296P
R19: 100k; 0207/10
R20, R21: 1K; 0207/7
R22: 22K; 0207/10
R24, R34: 200k; 0207/10
R26: 3,3K; 0207/10
R28: 66,5K; 0207/7
R32, R33: 5K; RTRIM3296P
U$1, U$2: MCP3208_DIP; MCP2308

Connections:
AREF_-10: R2.2, R3.2, R14.2, R15.2, R24.2, R25.2, R34.2, R35.2; also elsewhere on the board
BCH0: U$2.P$1 (CH0); also elsewhere on the board
BCH1: U$2.P$2 (CH1); also elsewhere on the board
BCH2: U$2.P$3 (CH2); also elsewhere on the board
BCH3: U$2.P$4 (CH3); also elsewhere on the board
BCH4: U$2.P$5 (CH4); also elsewhere on the board
BCH5: U$2.P$6 (CH5); also elsewhere on the board
BCH6: U$2.P$7 (CH6); also elsewhere on the board
BCH7: U$2.P$8 (CH7); also elsewhere on the board
CH0: C11.2, IC2.14 (OUT), R6.1, U$1.P$1 (CH0)
CH1: C15.2, IC2.8 (OUT), R16.1, U$1.P$3 (CH2)
CH2: C12.2, IC2.7 (OUT), R7.1, U$1.P$4 (CH3)
CH3: C16.2, IC2.1 (OUT), R17.1, U$1.P$2 (CH1)
CH4: C18.2, IC3.8 (OUT), R29.1, U$1.P$7 (CH6)
CH5: C17.2, IC3.7 (OUT), R28.1, U$1.P$8 (CH7)
CH6: C19.2, IC3.1 (OUT), R36.1, U$1.P$5 (CH4)
CH7: C20.2, IC3.14 (OUT), R37.1, U$1.P$6 (CH5)
CM: IC1.3 (+IN), IC1.5 (+IN), OFFSET.1, OFFSET.2; also elsewhere on the board
CS1: U$1.P$10 (CS/SHDN); also elsewhere on the board
CS2: U$2.P$10 (CS/SHDN); also elsewhere on the board
GND: AGND1.2, AGND2.2, C7.2, C10.1; also elsewhere on the board
GNDA: AGND1.1, C1.1, C2.1, C3.2, C4.-, C5.2, C6.-, C8.2, C9.2, IC2.3 (+IN), IC2.5 (+IN), IC2.10 (+IN), IC2.11 (V-), IC2.12 (+IN), IC3.3 (+IN), IC3.5 (+IN), IC3.10 (+IN), IC3.11 (V-), IC3.12 (+IN), U$1.P$9 (DGND), U$1.P$14 (AGND), U$2.P$9 (DGND), U$2.P$14 (AGND); also elsewhere on the board
GNDB: AGND2.1, AUDIORAW.1, JP-AUDIO.2, JP-AUDIO.8, OFFSET.3, R12.1 (E), R13.1 (E), R32.1 (E), R32.2 (S), R33.1 (E), R33.2 (S)
IN1: JP-AUDIO.1, R10.2
IN2: JP-AUDIO.7, R11.2
INL1: R8.2; also elsewhere on the board
INL2: R18.2; also elsewhere on the board
INL3: R30.2; also elsewhere on the board
INL4: R38.2; also elsewhere on the board
INL5: R39.2; also elsewhere on the board
INL6: R31.2; also elsewhere on the board
INL7: R19.2; also elsewhere on the board
INL8: R9.2; also elsewhere on the board
LIN-: AUDIORAW.2, C14.+; also elsewhere on the board
MISO: U$1.P$12 (DOUT), U$2.P$12 (DOUT); also elsewhere on the board
MOSI: U$1.P$11 (DIN), U$2.P$11 (DIN); also elsewhere on the board
unnamed: C15.1, IC2.9 (-IN), R14.1, R16.2, R18.1
unnamed: R26.2, R32.3 (A)
unnamed: C16.1, IC2.2 (-IN), R15.1, R17.2, R19.1
unnamed: IC1.13 (-IN), R22.2, R26.1
unnamed: IC1.14 (OUT), R21.2, R22.1
unnamed: AU-IN.2, C13.-, R12.2 (S)
unnamed: R27.2, R33.3 (A)
unnamed: IC1.9 (-IN), R23.2, R27.1
unnamed: C11.1, IC2.13 (-IN), R2.1, R6.2, R8.1
unnamed: IC1.8 (OUT), R20.2, R23.1
unnamed: IC1.10 (+IN), JP-AU.2
unnamed: IC1.12 (+IN), JP-AU.1
unnamed: C12.1, IC2.6 (-IN), R3.1, R7.2, R9.1
unnamed: AU-IN.1, C14.-, R13.2 (S)
unnamed: IC1.6 (-IN), R4.2, R10.1
unnamed: C19.1, IC3.2 (-IN), R34.1, R36.2, R38.1
unnamed: IC1.7 (OUT), R4.1, R12.3 (A)
unnamed: C20.1, IC3.13 (-IN), R35.1, R37.2, R39.1
unnamed: IC1.2 (-IN), R5.2, R11.1
unnamed: C17.1, IC3.6 (-IN), R24.1, R28.2, R30.1
unnamed: IC1.1 (OUT), R5.1, R13.3 (A)
unnamed: C18.1, IC3.9 (-IN), R25.1, R29.2, R31.1
OUT1: JP-AUDIO.3, JP-AUDIO.4, R21.1
OUT2: JP-AUDIO.5, JP-AUDIO.6, R20.1
RIN-: AUDIORAW.3, C13.+; also elsewhere on the board
SCK: U$1.P$13 (CLK), U$2.P$13 (CLK); also elsewhere on the board
VCC: C7.1, IC1.4 (V+); also elsewhere on the board
VDD: C1.2, C2.2, R1.1, U$1.P$16 (VDD), U$2.P$16 (VDD); also elsewhere on the board
VDDAA: C3.1, C4.+, C5.1, C6.+, C8.1, C9.1, IC2.4 (V+), IC3.4 (V+), R1.2, U$1.P$15 (VREF), U$2.P$15 (VREF); also elsewhere on the board
VEE: C10.2, IC1.11 (V-); also elsewhere on the board

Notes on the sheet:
-5.0 to 5.0
0.0 to 5.0
1.1
Paul 2015
contact@irieelectronics.de

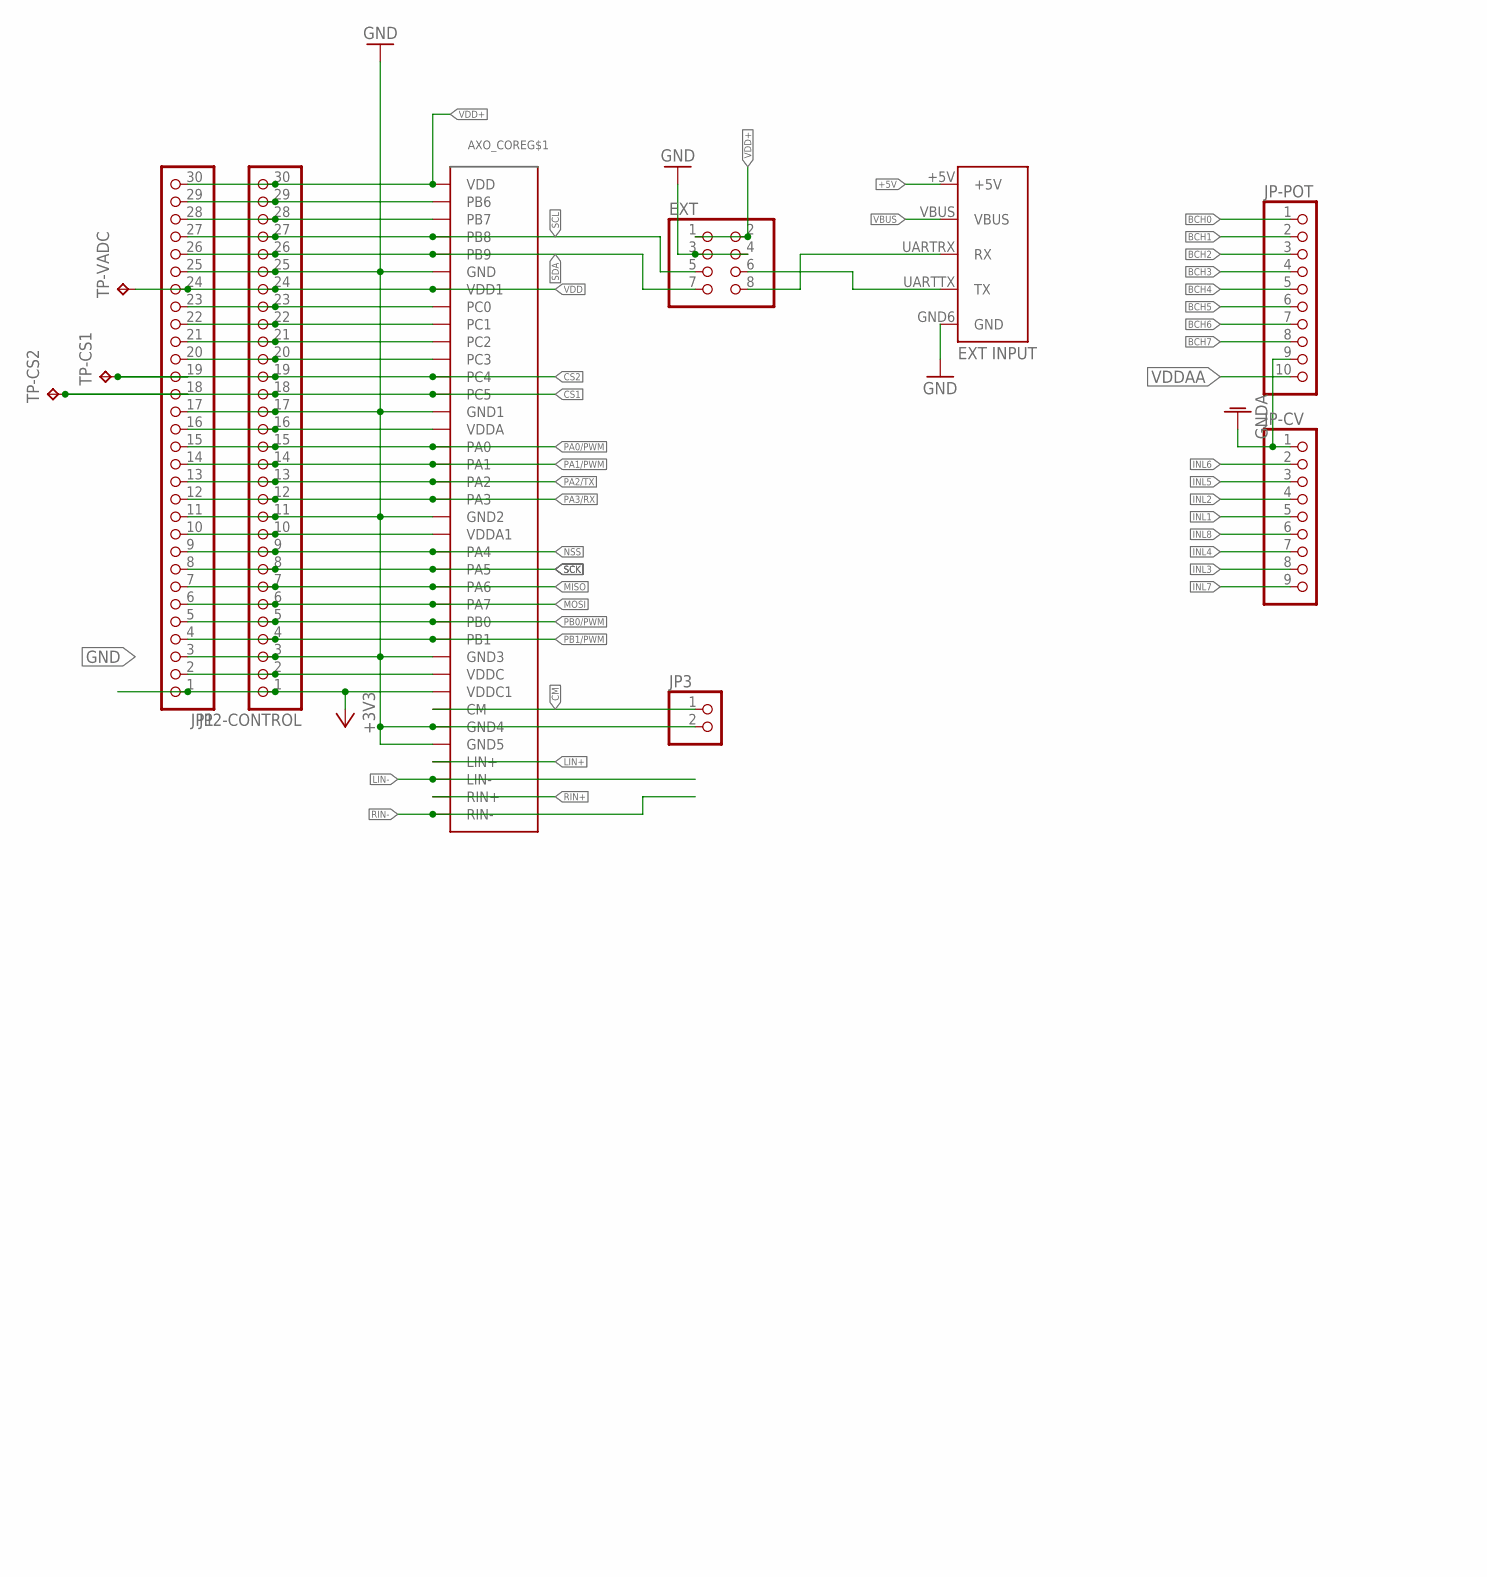
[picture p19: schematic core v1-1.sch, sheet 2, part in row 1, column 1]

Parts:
AXO_CORE: AXO-CORE; AXOLOTI-CORE
EXT: PINHD-2X4_2.54; 2X04
JP1, JP2-CONTROL: PINHD-1X30; 1X30
JP3: PINHD-1X2_2.54; 1X02
JP-CV: PINHD-1X9_2.54; 1X09
JP-POT: PINHD-1X10_2.54; 1X10
TP-CS1, TP-CS2: TPTP10R; TP10R
TP-VADC: TPTP10R; TP10R

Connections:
+3V3: AXO_CORE.VDDC1, JP1.1, JP2-CONTROL.1
+5V: AXO_CORE.+5V; also elsewhere on the board
BCH0: JP-POT.1; also elsewhere on the board
BCH1: JP-POT.2; also elsewhere on the board
BCH2: JP-POT.3; also elsewhere on the board
BCH3: JP-POT.4; also elsewhere on the board
BCH4: JP-POT.5; also elsewhere on the board
BCH5: JP-POT.6; also elsewhere on the board
BCH6: JP-POT.7; also elsewhere on the board
BCH7: JP-POT.8; also elsewhere on the board
CM: AXO_CORE.CM, JP3.1; also elsewhere on the board
CS1: AXO_CORE.PC5, JP1.18, JP2-CONTROL.18, TP-CS2.TP; also elsewhere on the board
CS2: AXO_CORE.PC4, JP1.19, JP2-CONTROL.19, TP-CS1.TP; also elsewhere on the board
GND: AXO_CORE.GND, AXO_CORE.GND1, AXO_CORE.GND2 (GND3), AXO_CORE.GND3 (GND2), AXO_CORE.GND4, AXO_CORE.GND5, AXO_CORE.GND6 (GND), EXT.3, EXT.4, JP1.3, JP1.11, JP1.17, JP1.25, JP2-CONTROL.3, JP2-CONTROL.11, JP2-CONTROL.17, JP2-CONTROL.25, JP3.2; also elsewhere on the board
GNDA: JP-CV.1, JP-POT.9; also elsewhere on the board
INL1: JP-CV.5; also elsewhere on the board
INL2: JP-CV.4; also elsewhere on the board
INL3: JP-CV.8; also elsewhere on the board
INL4: JP-CV.7; also elsewhere on the board
INL5: JP-CV.3; also elsewhere on the board
INL6: JP-CV.2; also elsewhere on the board
INL7: JP-CV.9; also elsewhere on the board
INL8: JP-CV.6; also elsewhere on the board
LIN+: AXO_CORE.LIN+
LIN-: AXO_CORE.LIN-; also elsewhere on the board
MIDI/RX: AXO_CORE.UARTRX (RX), EXT.8
MIDI/TX: AXO_CORE.UARTTX (TX), EXT.6
MISO: AXO_CORE.PA6, JP1.7, JP2-CONTROL.7; also elsewhere on the board
MOSI: AXO_CORE.PA7, JP1.6, JP2-CONTROL.6; also elsewhere on the board
unnamed: AXO_CORE.VDDC, JP1.2, JP2-CONTROL.2
unnamed: AXO_CORE.VDDA1, JP1.10, JP2-CONTROL.10
unnamed: AXO_CORE.VDDA, JP1.16, JP2-CONTROL.16
unnamed: AXO_CORE.PC3, JP1.20, JP2-CONTROL.20
unnamed: AXO_CORE.PC2, JP1.21, JP2-CONTROL.21
unnamed: AXO_CORE.PC1, JP1.22, JP2-CONTROL.22
unnamed: AXO_CORE.PC0, JP1.23, JP2-CONTROL.23
unnamed: AXO_CORE.PB7, JP1.28, JP2-CONTROL.28
unnamed: AXO_CORE.PB6, JP1.29, JP2-CONTROL.29
NSS: AXO_CORE.PA4, JP1.9, JP2-CONTROL.9
PA0/PWM: AXO_CORE.PA0, JP1.15, JP2-CONTROL.15
PA1/PWM: AXO_CORE.PA1, JP1.14, JP2-CONTROL.14
PA2/TX: AXO_CORE.PA2, JP1.13, JP2-CONTROL.13
PA3/RX: AXO_CORE.PA3, JP1.12, JP2-CONTROL.12
PB0/PWM: AXO_CORE.PB0, JP1.5, JP2-CONTROL.5
PB1/PWM: AXO_CORE.PB1, JP1.4, JP2-CONTROL.4
RIN+: AXO_CORE.RIN+
RIN-: AXO_CORE.RIN-; also elsewhere on the board
SCK: AXO_CORE.PA5, JP1.8, JP2-CONTROL.8; also elsewhere on the board
SCL: AXO_CORE.PB8, EXT.5, JP1.27, JP2-CONTROL.27
SDA: AXO_CORE.PB9, EXT.7, JP1.26, JP2-CONTROL.26
VBUS: AXO_CORE.VBUS; also elsewhere on the board
VDD: AXO_CORE.VDD1, JP1.24, JP2-CONTROL.24, TP-VADC.TP; also elsewhere on the board
VDD+: AXO_CORE.VDD, EXT.1, EXT.2, JP1.30, JP2-CONTROL.30
VDDAA: JP-POT.10; also elsewhere on the board

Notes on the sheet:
Paul 2015
contact@irieelectronics.de
1.1

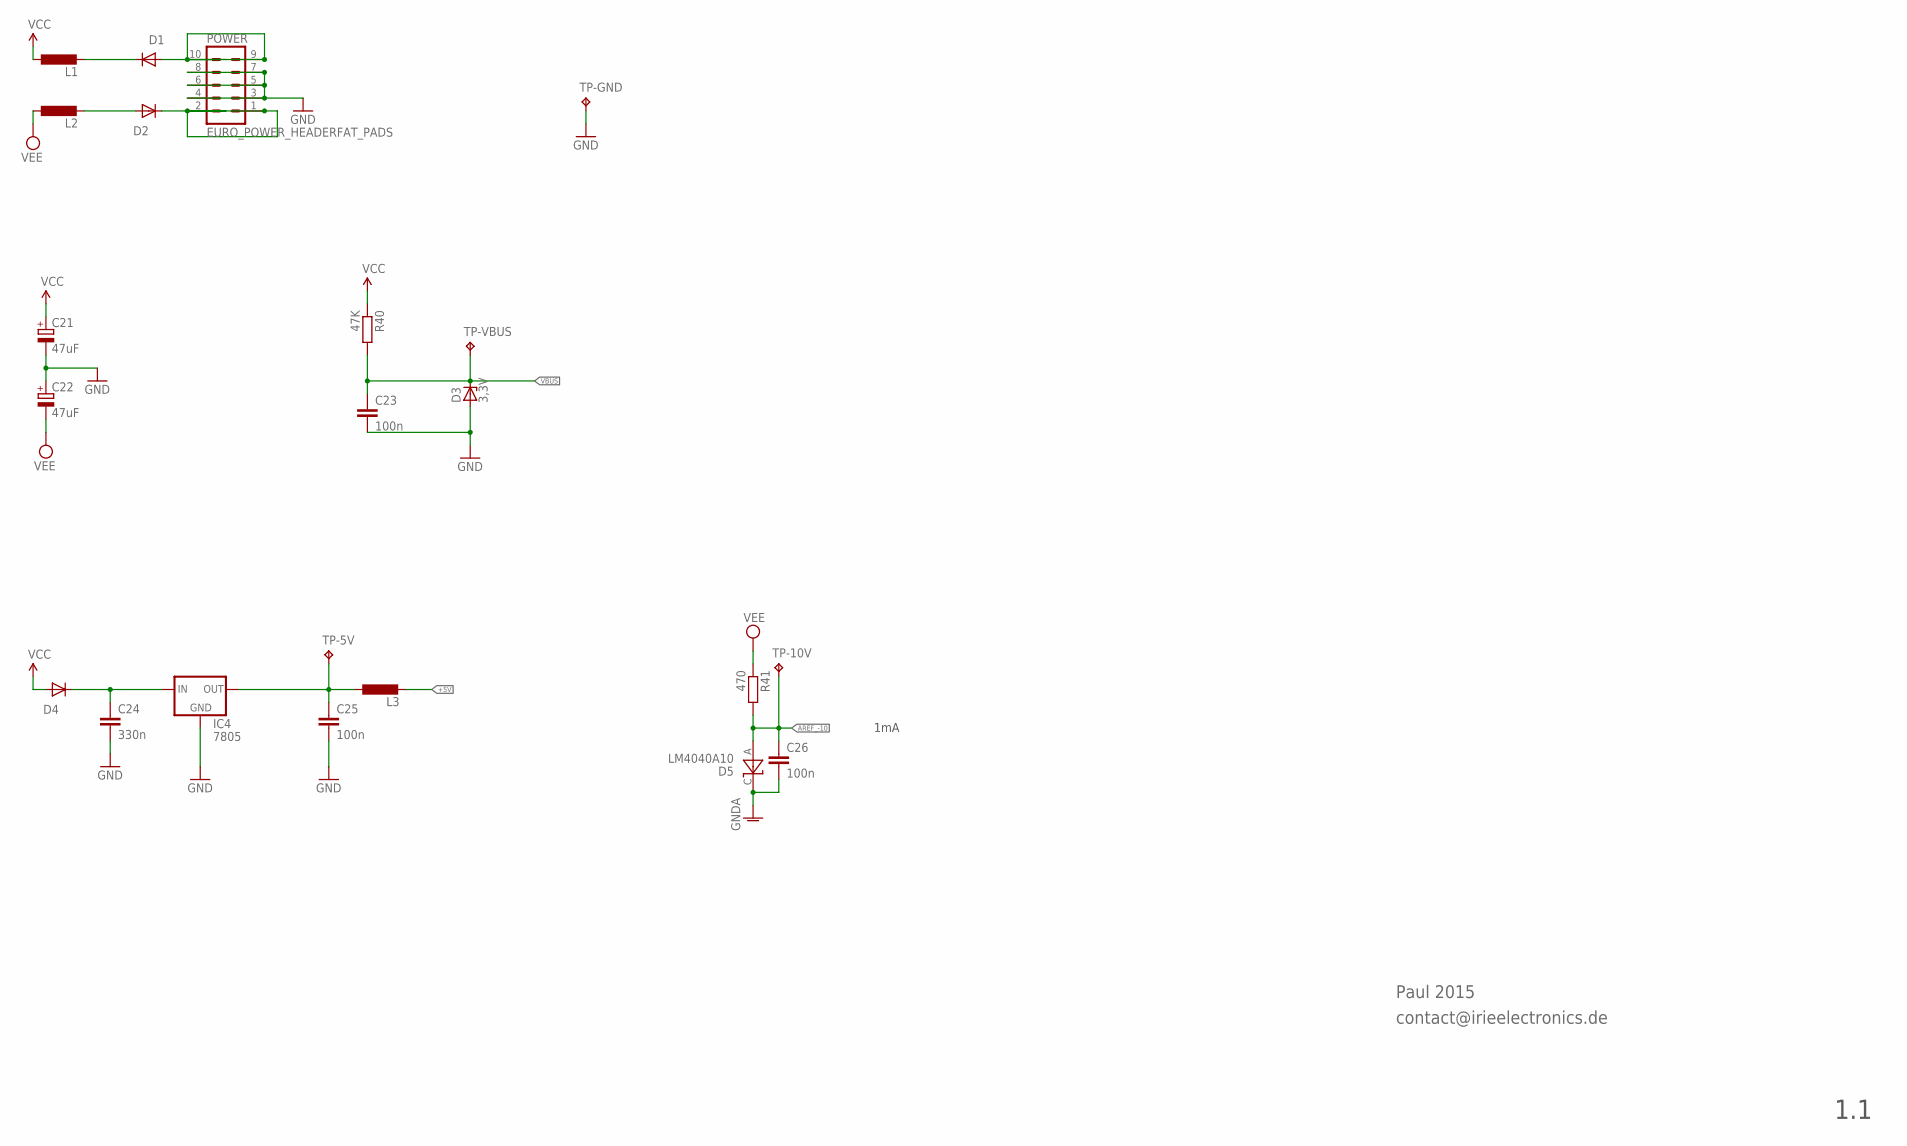
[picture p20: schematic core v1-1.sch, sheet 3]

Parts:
C21, C22: 47uF; E2-5
C23, C25, C26: 100n; C025-025X050
C24: 330n; C025-025X050
D1, D2: 1N5819; DO35-10
D3: 3,3V; DO35Z10
D4: 1N5819HW; DO35-10
D5: LM4040A10; TO-92
IC4: 7805; 78MXXS
L1, L2, L3: L-EU0207/10; 0207/10
POWER: EURO_POWER_HEADERFAT_PADS; EURO_PWR_HEADER_FAT
R40: 47K; 0207/7
R41: 470; 0207/10
TP-5V, TP-10V: TPTP10R; TP10R
TP-GND: TPPAD1-13; P1-13
TP-VBUS: TPTP10R; TP10R

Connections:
+5V: L3.2; also elsewhere on the board
+5V_RAW: C25.1, IC4.OUT, L3.1, TP-5V.TP
AREF_-10: C26.1, D5.A, R41.2, TP-10V.TP; also elsewhere on the board
GND: C21.-, C22.+, C23.2, C24.2, C25.2, D3.A, IC4.GND, POWER.3, POWER.4, POWER.5, POWER.6, POWER.7, POWER.8, TP-GND.TP; also elsewhere on the board
GNDA: C26.2, D5.C; also elsewhere on the board
unnamed: D1.C, L1.2
unnamed: D2.A, L2.2
unnamed: C24.1, D4.C, IC4.IN
unnamed: D1.A, POWER.9, POWER.10
unnamed: D2.C, POWER.1, POWER.2
VBUS: C23.1, D3.C, R40.2, TP-VBUS.TP; also elsewhere on the board
VCC: C21.+, D4.A, L1.1, R40.1; also elsewhere on the board
VEE: C22.-, L2.1, R41.1; also elsewhere on the board

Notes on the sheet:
1mA
Paul 2015
contact@irieelectronics.de
1.1

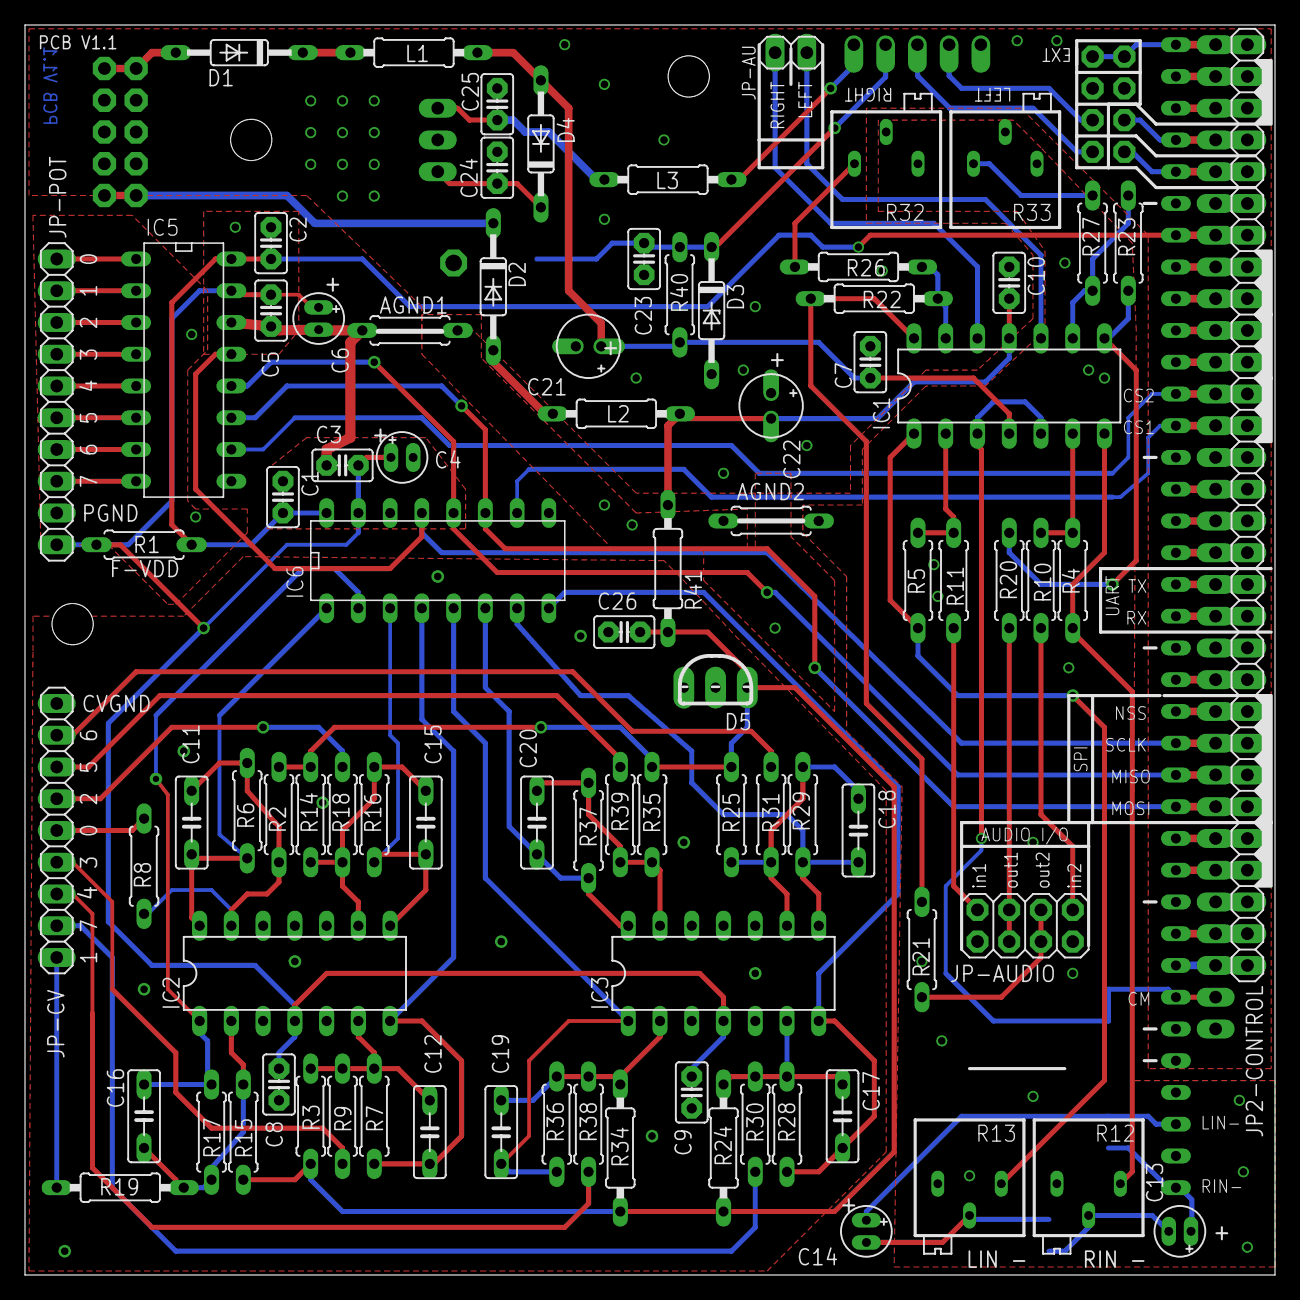
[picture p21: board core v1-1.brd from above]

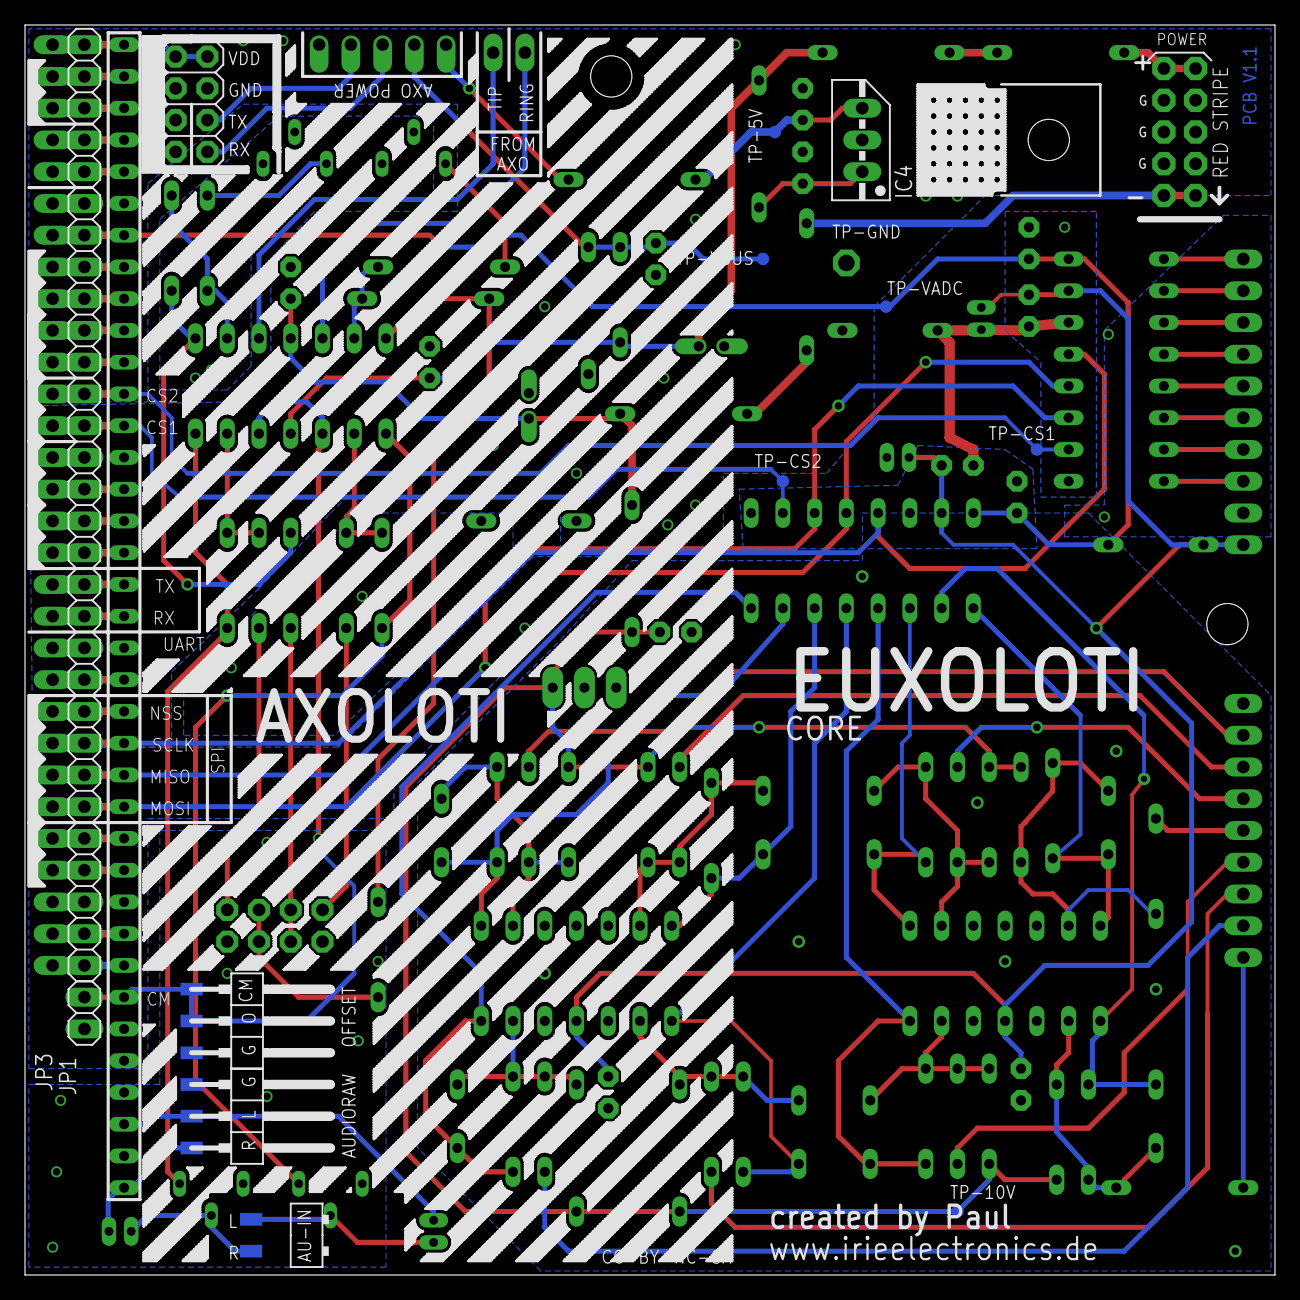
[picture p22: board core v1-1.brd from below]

Board: 4 copper layers, 100.0 x 100.0 mm, 104 parts (16 on the bottom side), 96 nets.

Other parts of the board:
BOTTOM_ARTWORK: LABEL_COREBOTTOM

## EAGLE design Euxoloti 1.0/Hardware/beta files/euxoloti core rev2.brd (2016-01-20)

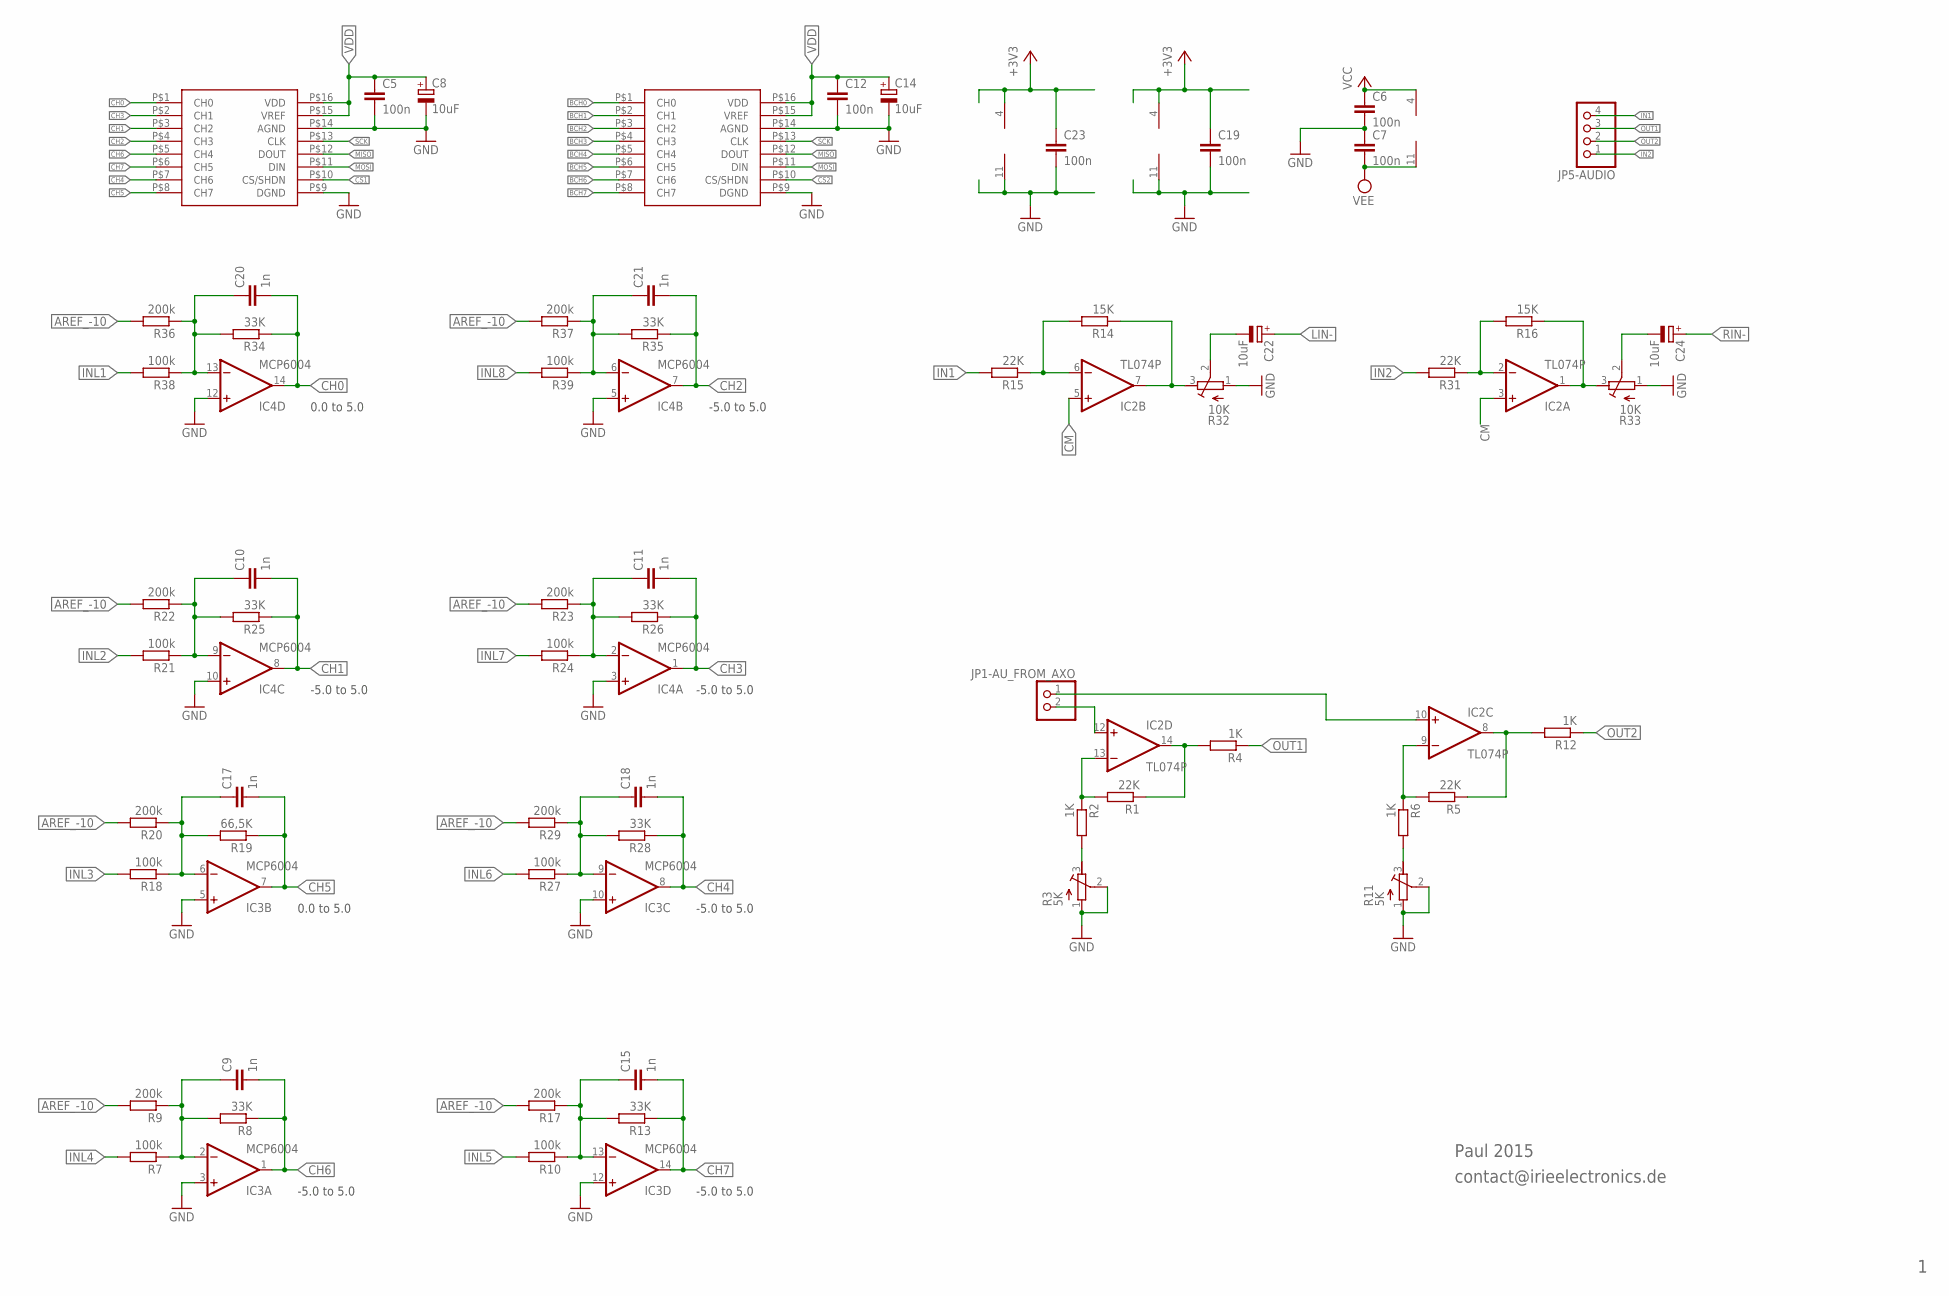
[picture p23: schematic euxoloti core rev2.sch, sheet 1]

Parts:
C5, C6, C7, C12, C19, C23: 100n; C025-025X050
C8, C14, C22, C24: 10uF; E1,8-4
C9, C10, C11, C15, C17, C18, C20, C21: 1n; C050-025X075
IC2: TL074P; DIL14
IC3, IC4: MCP6004; DIL14
JP1-AU_FROM_AXO: PINHD-1X2/90; 1X02/90
JP5-AUDIO: PINHD-1X4_2.54; 1X04
R1: 22K; 0207/10
R2: 1K; 0207/12
R3, R11: 5K; RTRIM3296P
R4, R6: 1K; 0207/7
R5, R15, R31: 22K; 0207/7
R7, R10, R18, R21, R27, R38, R39: 100k; 0207/7
R8, R13, R25, R26, R28, R34, R35: 33K; 0207/7
R9, R20: 200k; 0207/10
R12: 1K; 0207/10
R14, R16: 15K; 0207/7
R17, R22, R23, R29, R36, R37: 200k; 0207/7
R19: 66,5K; 0207/7
R24: 100k; 0207/10
R32, R33: 10K; RTRIM3296P
U$4, U$5: MCP3208_DIP; MCP2308

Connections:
+3V3: C19.1, C23.1, IC3.4 (V+), IC4.4 (V+); also elsewhere on the board
AREF_-10: R9.2, R17.2, R20.2, R22.2, R23.2, R29.2, R36.2, R37.2; also elsewhere on the board
BCH0: U$5.P$1 (CH0); also elsewhere on the board
BCH1: U$5.P$2 (CH1); also elsewhere on the board
BCH2: U$5.P$3 (CH2); also elsewhere on the board
BCH3: U$5.P$4 (CH3); also elsewhere on the board
BCH4: U$5.P$5 (CH4); also elsewhere on the board
BCH5: U$5.P$6 (CH5); also elsewhere on the board
BCH6: U$5.P$7 (CH6); also elsewhere on the board
BCH7: U$5.P$8 (CH7); also elsewhere on the board
CH0: C20.2, IC4.14 (OUT), R34.1, U$4.P$1 (CH0)
CH1: C10.2, IC4.8 (OUT), R25.1, U$4.P$3 (CH2)
CH2: C21.2, IC4.7 (OUT), R35.1, U$4.P$4 (CH3)
CH3: C11.2, IC4.1 (OUT), R26.1, U$4.P$2 (CH1)
CH4: C18.2, IC3.8 (OUT), R28.1, U$4.P$7 (CH6)
CH5: C17.2, IC3.7 (OUT), R19.1, U$4.P$8 (CH7)
CH6: C9.2, IC3.1 (OUT), R8.1, U$4.P$5 (CH4)
CH7: C15.2, IC3.14 (OUT), R13.1, U$4.P$6 (CH5)
CM: IC2.3 (+IN), IC2.5 (+IN); also elsewhere on the board
CS1: U$4.P$10 (CS/SHDN); also elsewhere on the board
CS2: U$5.P$10 (CS/SHDN); also elsewhere on the board
GND: C5.2, C6.2, C7.1, C8.-, C12.2, C14.-, C19.2, C23.2, IC3.3 (+IN), IC3.5 (+IN), IC3.10 (+IN), IC3.11 (V-), IC3.12 (+IN), IC4.3 (+IN), IC4.5 (+IN), IC4.10 (+IN), IC4.11 (V-), IC4.12 (+IN), R3.1 (E), R3.2 (S), R11.1 (E), R11.2 (S), R32.1 (E), R33.1 (E), U$4.P$9 (DGND), U$4.P$14 (AGND), U$5.P$9 (DGND), U$5.P$14 (AGND); also elsewhere on the board
IN1: JP5-AUDIO.4, R15.2
IN2: JP5-AUDIO.1, R31.2
INL1: R38.2; also elsewhere on the board
INL2: R21.2; also elsewhere on the board
INL3: R18.2; also elsewhere on the board
INL4: R7.2; also elsewhere on the board
INL5: R10.2; also elsewhere on the board
INL6: R27.2; also elsewhere on the board
INL7: R24.2; also elsewhere on the board
INL8: R39.2; also elsewhere on the board
LIN-: C22.+; also elsewhere on the board
MISO: U$4.P$12 (DOUT), U$5.P$12 (DOUT); also elsewhere on the board
MOSI: U$4.P$11 (DIN), U$5.P$11 (DIN); also elsewhere on the board
unnamed: C10.1, IC4.9 (-IN), R21.1, R22.1, R25.2
unnamed: R2.2, R3.3 (A)
unnamed: C11.1, IC4.2 (-IN), R23.1, R24.1, R26.2
unnamed: IC2.13 (-IN), R1.2, R2.1
unnamed: IC2.14 (OUT), R1.1, R4.2
unnamed: C22.-, R32.2 (S)
unnamed: R6.2, R11.3 (A)
unnamed: IC2.9 (-IN), R5.2, R6.1
unnamed: C20.1, IC4.13 (-IN), R34.2, R36.1, R38.1
unnamed: IC2.8 (OUT), R5.1, R12.2
unnamed: IC2.10 (+IN), JP1-AU_FROM_AXO.1
unnamed: IC2.12 (+IN), JP1-AU_FROM_AXO.2
unnamed: C21.1, IC4.6 (-IN), R35.2, R37.1, R39.1
unnamed: C24.-, R33.2 (S)
unnamed: IC2.6 (-IN), R14.2, R15.1
unnamed: C9.1, IC3.2 (-IN), R7.1, R8.2, R9.1
unnamed: IC2.7 (OUT), R14.1, R32.3 (A)
unnamed: C15.1, IC3.13 (-IN), R10.1, R13.2, R17.1
unnamed: IC2.2 (-IN), R16.2, R31.1
unnamed: C17.1, IC3.6 (-IN), R18.1, R19.2, R20.1
unnamed: IC2.1 (OUT), R16.1, R33.3 (A)
unnamed: C18.1, IC3.9 (-IN), R27.1, R28.2, R29.1
OUT1: JP5-AUDIO.3, R4.1
OUT2: JP5-AUDIO.2, R12.1
RIN-: C24.+; also elsewhere on the board
SCK: U$4.P$13 (CLK), U$5.P$13 (CLK); also elsewhere on the board
VCC: C6.1, IC2.4 (V+); also elsewhere on the board
VDD: C5.1, C8.+, C12.1, C14.+, U$4.P$15 (VREF), U$4.P$16 (VDD), U$5.P$15 (VREF), U$5.P$16 (VDD); also elsewhere on the board
VEE: C7.2, IC2.11 (V-); also elsewhere on the board

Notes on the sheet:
-5.0 to 5.0
0.0 to 5.0
Paul 2015
contact@irieelectronics.de

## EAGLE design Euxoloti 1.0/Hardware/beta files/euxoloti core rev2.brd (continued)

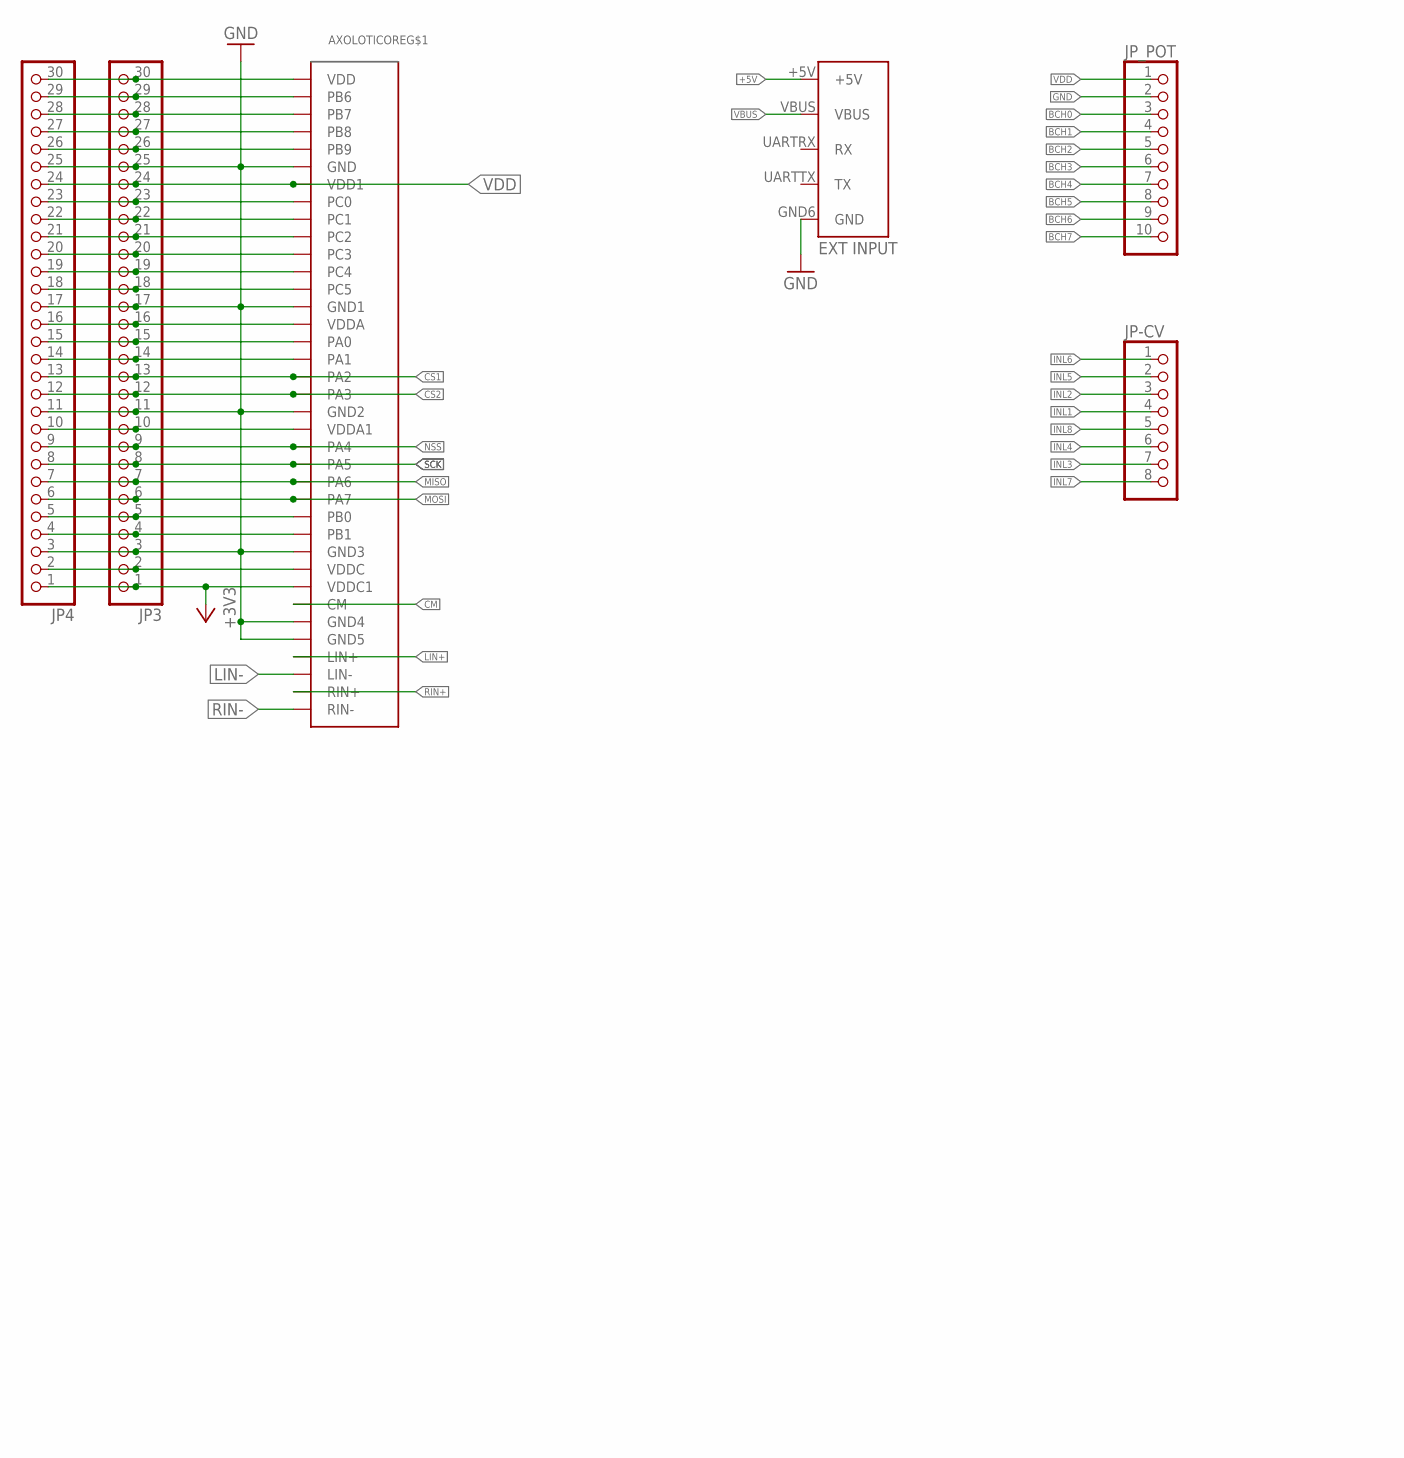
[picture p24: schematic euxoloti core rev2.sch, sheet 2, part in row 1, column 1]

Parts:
AXOLOTICORE: AXOLOTI-CORE
JP3, JP4: PINHD-1X30; 1X30
JP-CV: PINHD-1X8_2.54; 1X08
JP_POT: PINHD-1X10; 1X10

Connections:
+3V3: AXOLOTICORE.VDDC1, JP3.1, JP4.1; also elsewhere on the board
+5V: AXOLOTICORE.+5V; also elsewhere on the board
BCH0: JP_POT.3; also elsewhere on the board
BCH1: JP_POT.4; also elsewhere on the board
BCH2: JP_POT.5; also elsewhere on the board
BCH3: JP_POT.6; also elsewhere on the board
BCH4: JP_POT.7; also elsewhere on the board
BCH5: JP_POT.8; also elsewhere on the board
BCH6: JP_POT.9; also elsewhere on the board
BCH7: JP_POT.10; also elsewhere on the board
CM: AXOLOTICORE.CM; also elsewhere on the board
CS1: AXOLOTICORE.PA2, JP3.13, JP4.13; also elsewhere on the board
CS2: AXOLOTICORE.PA3, JP3.12, JP4.12; also elsewhere on the board
GND: AXOLOTICORE.GND, AXOLOTICORE.GND1, AXOLOTICORE.GND2 (GND3), AXOLOTICORE.GND3 (GND2), AXOLOTICORE.GND4, AXOLOTICORE.GND5, AXOLOTICORE.GND6 (GND), JP3.3, JP3.11, JP3.17, JP3.25, JP4.3, JP4.11, JP4.17, JP4.25, JP_POT.2; also elsewhere on the board
INL1: JP-CV.4; also elsewhere on the board
INL2: JP-CV.3; also elsewhere on the board
INL3: JP-CV.7; also elsewhere on the board
INL4: JP-CV.6; also elsewhere on the board
INL5: JP-CV.2; also elsewhere on the board
INL6: JP-CV.1; also elsewhere on the board
INL7: JP-CV.8; also elsewhere on the board
INL8: JP-CV.5; also elsewhere on the board
LIN+: AXOLOTICORE.LIN+
LIN-: AXOLOTICORE.LIN-; also elsewhere on the board
MISO: AXOLOTICORE.PA6, JP3.7, JP4.7; also elsewhere on the board
MOSI: AXOLOTICORE.PA7, JP3.6, JP4.6; also elsewhere on the board
unnamed: AXOLOTICORE.PB1, JP3.4, JP4.4
unnamed: AXOLOTICORE.PB0, JP3.5, JP4.5
unnamed: AXOLOTICORE.VDDC, JP3.2, JP4.2
unnamed: AXOLOTICORE.VDDA1, JP3.10, JP4.10
unnamed: AXOLOTICORE.PA1, JP3.14, JP4.14
unnamed: AXOLOTICORE.PA0, JP3.15, JP4.15
unnamed: AXOLOTICORE.VDDA, JP3.16, JP4.16
unnamed: AXOLOTICORE.PC5, JP3.18, JP4.18
unnamed: AXOLOTICORE.PC4, JP3.19, JP4.19
unnamed: AXOLOTICORE.PC3, JP3.20, JP4.20
unnamed: AXOLOTICORE.PC2, JP3.21, JP4.21
unnamed: AXOLOTICORE.PC1, JP3.22, JP4.22
unnamed: AXOLOTICORE.PC0, JP3.23, JP4.23
unnamed: AXOLOTICORE.PB9, JP3.26, JP4.26
unnamed: AXOLOTICORE.PB8, JP3.27, JP4.27
unnamed: AXOLOTICORE.PB7, JP3.28, JP4.28
unnamed: AXOLOTICORE.PB6, JP3.29, JP4.29
NSS: AXOLOTICORE.PA4, JP3.9, JP4.9
RIN+: AXOLOTICORE.RIN+
RIN-: AXOLOTICORE.RIN-; also elsewhere on the board
SCK: AXOLOTICORE.PA5, JP3.8, JP4.8; also elsewhere on the board
VBUS: AXOLOTICORE.VBUS; also elsewhere on the board
VDD: AXOLOTICORE.VDD1, JP3.24, JP4.24, JP_POT.1; also elsewhere on the board
VDD+: AXOLOTICORE.VDD, JP3.30, JP4.30

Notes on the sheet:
Paul 2015
contact@irieelectronics.de

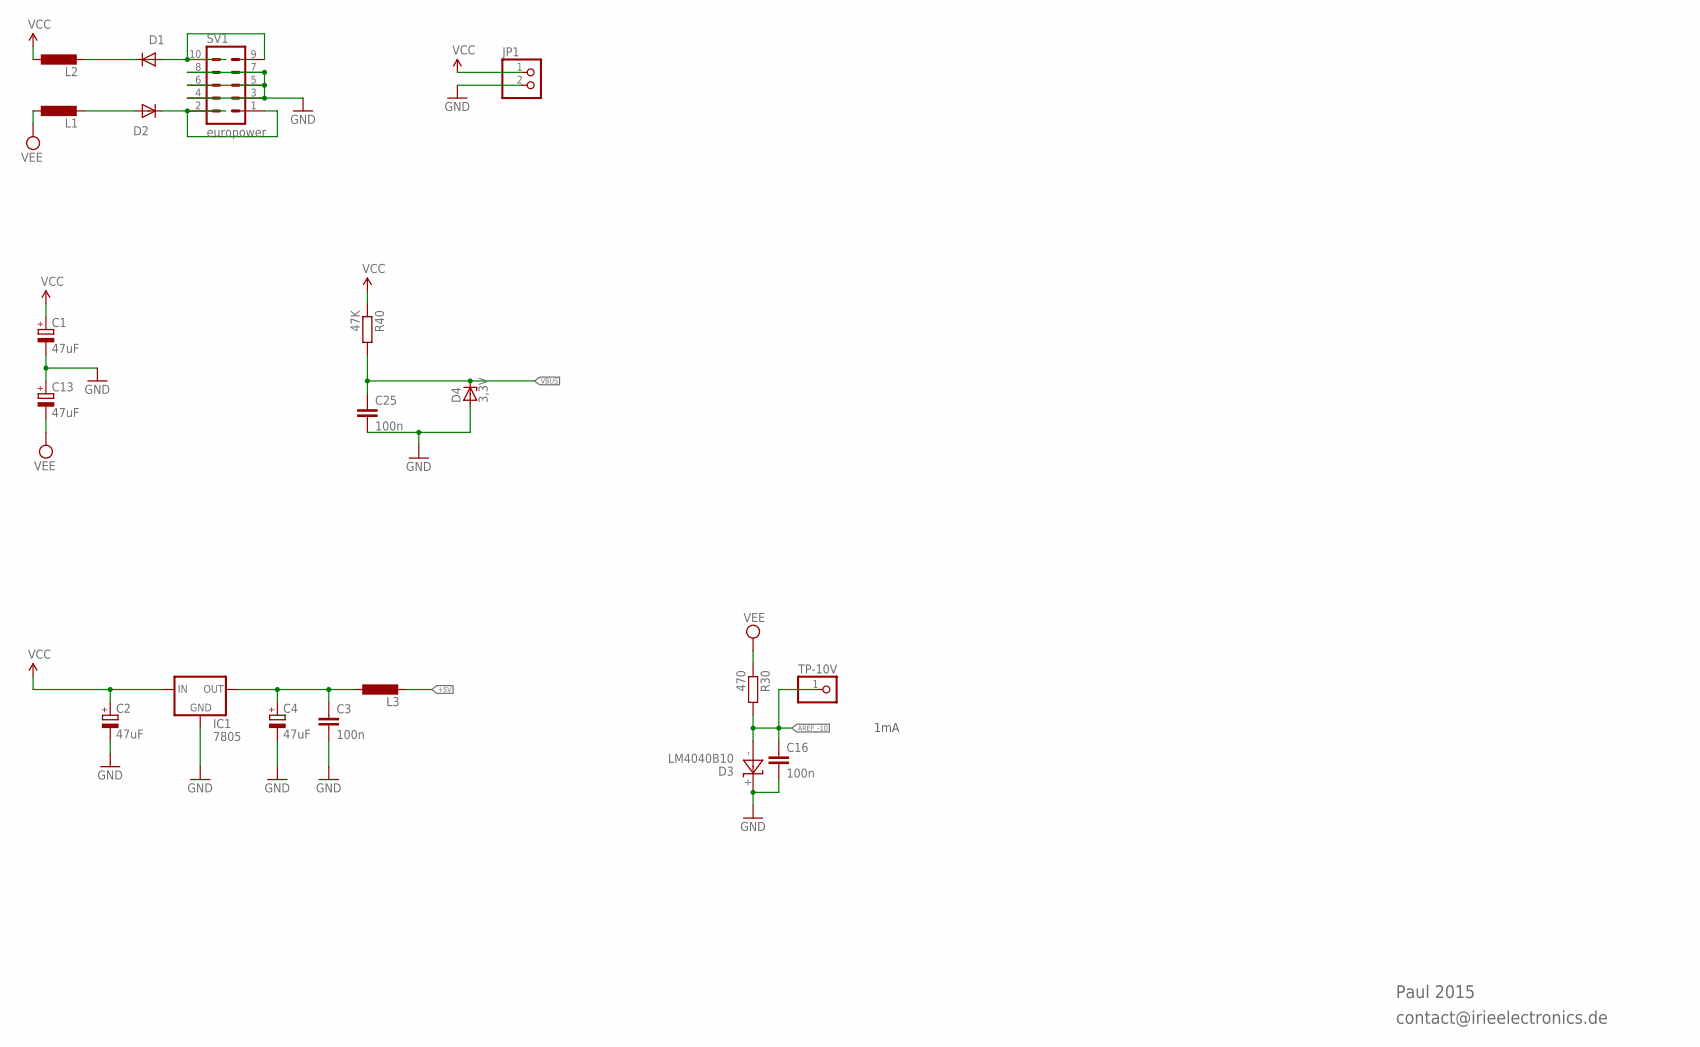
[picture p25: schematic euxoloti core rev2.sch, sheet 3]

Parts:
C1, C2, C13: 47uF; E2-5
C3, C16, C25: 100n; C025-025X050
C4: 47uF; E2,5-5
D1, D2: 1N5819HW; DO35-10
D3: LM4040B10; TO-92
D4: 3,3V; DO35Z10
IC1: 7805; 78XXS
JP1: PINHD-1X2; 1X02
L1, L2, L3: L-EU0207/10; 0207/10
R30: 470; 0207/12
R40: 47K; 0207/7
SV1: europower; EURO_PWR_HEADER_FAT
TP-10V: PINHD-1X1_2.54; 1X01

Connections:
+5V: L3.2; also elsewhere on the board
+5V_RAW: C3.1, C4.+, IC1.OUT, L3.1
AREF_-10: C16.1, D3.-, R30.2, TP-10V.1; also elsewhere on the board
GND: C1.-, C2.-, C3.2, C4.-, C13.+, C16.2, C25.2, D3.+, D4.A, IC1.GND, JP1.2, SV1.3, SV1.4, SV1.5, SV1.6, SV1.7, SV1.8; also elsewhere on the board
unnamed: D1.C, L2.2
unnamed: D2.A, L1.2
unnamed: D1.A, SV1.9, SV1.10
unnamed: D2.C, SV1.1, SV1.2
VBUS: C25.1, D4.C, R40.2; also elsewhere on the board
VCC: C1.+, C2.+, IC1.IN, JP1.1, L2.1, R40.1; also elsewhere on the board
VEE: C13.-, L1.1, R30.1; also elsewhere on the board

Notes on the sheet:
1mA
Paul 2015
contact@irieelectronics.de

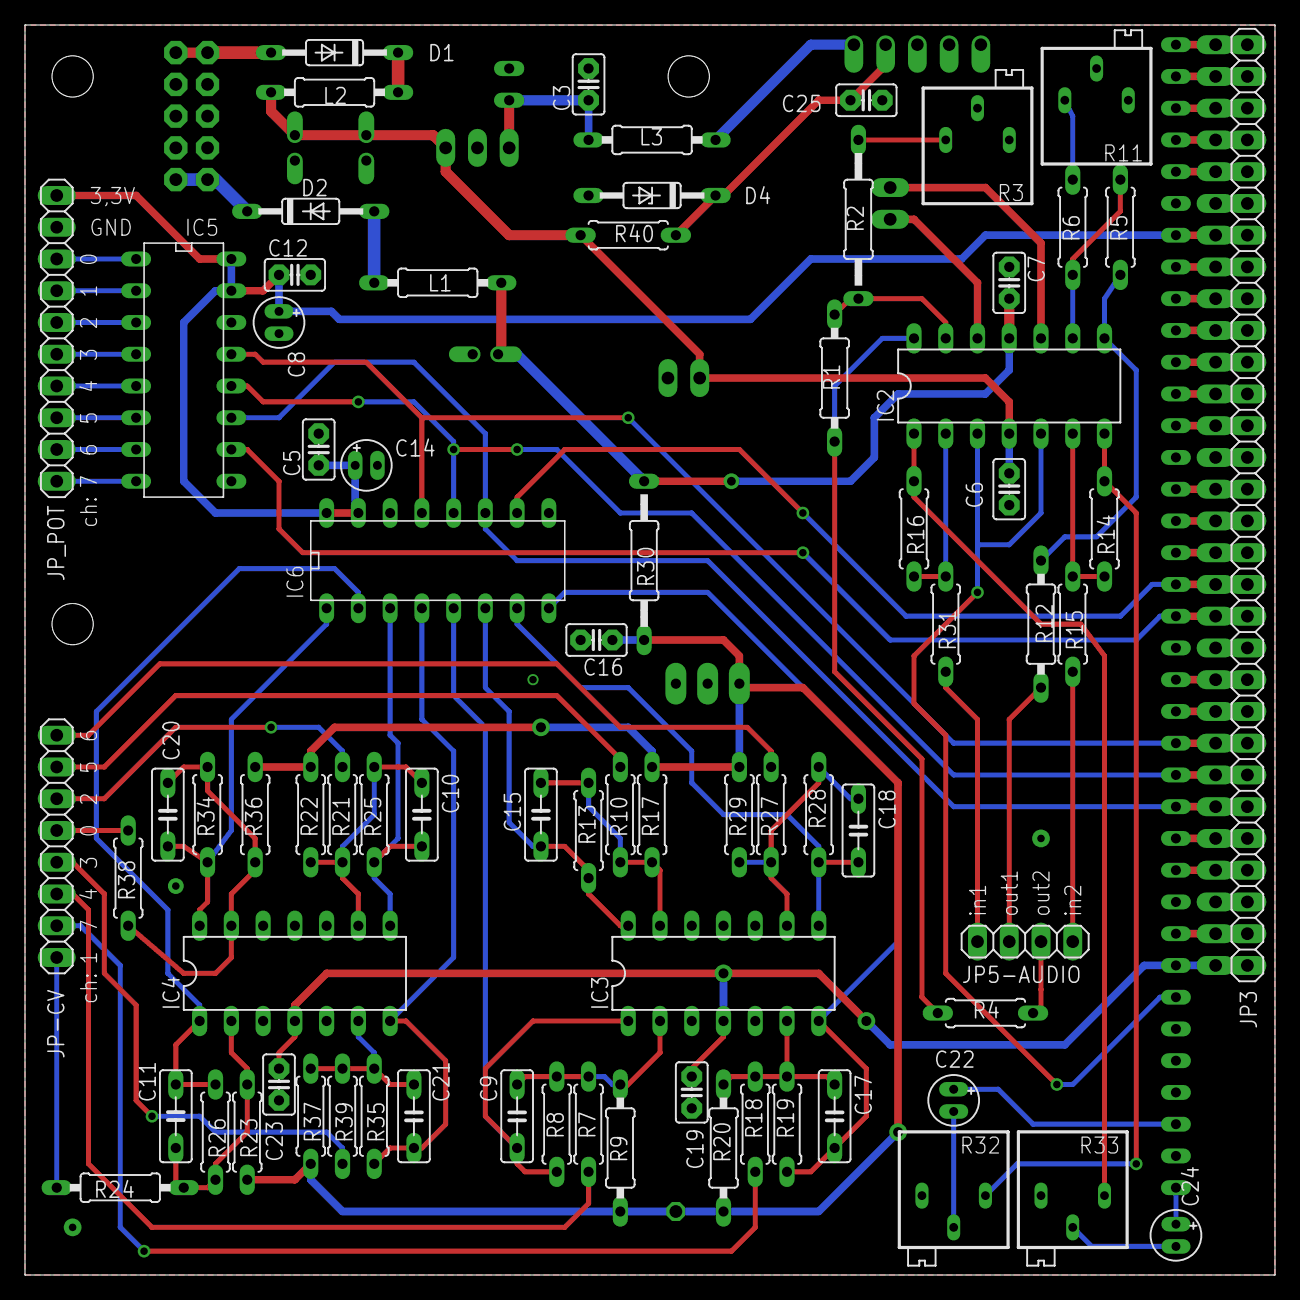
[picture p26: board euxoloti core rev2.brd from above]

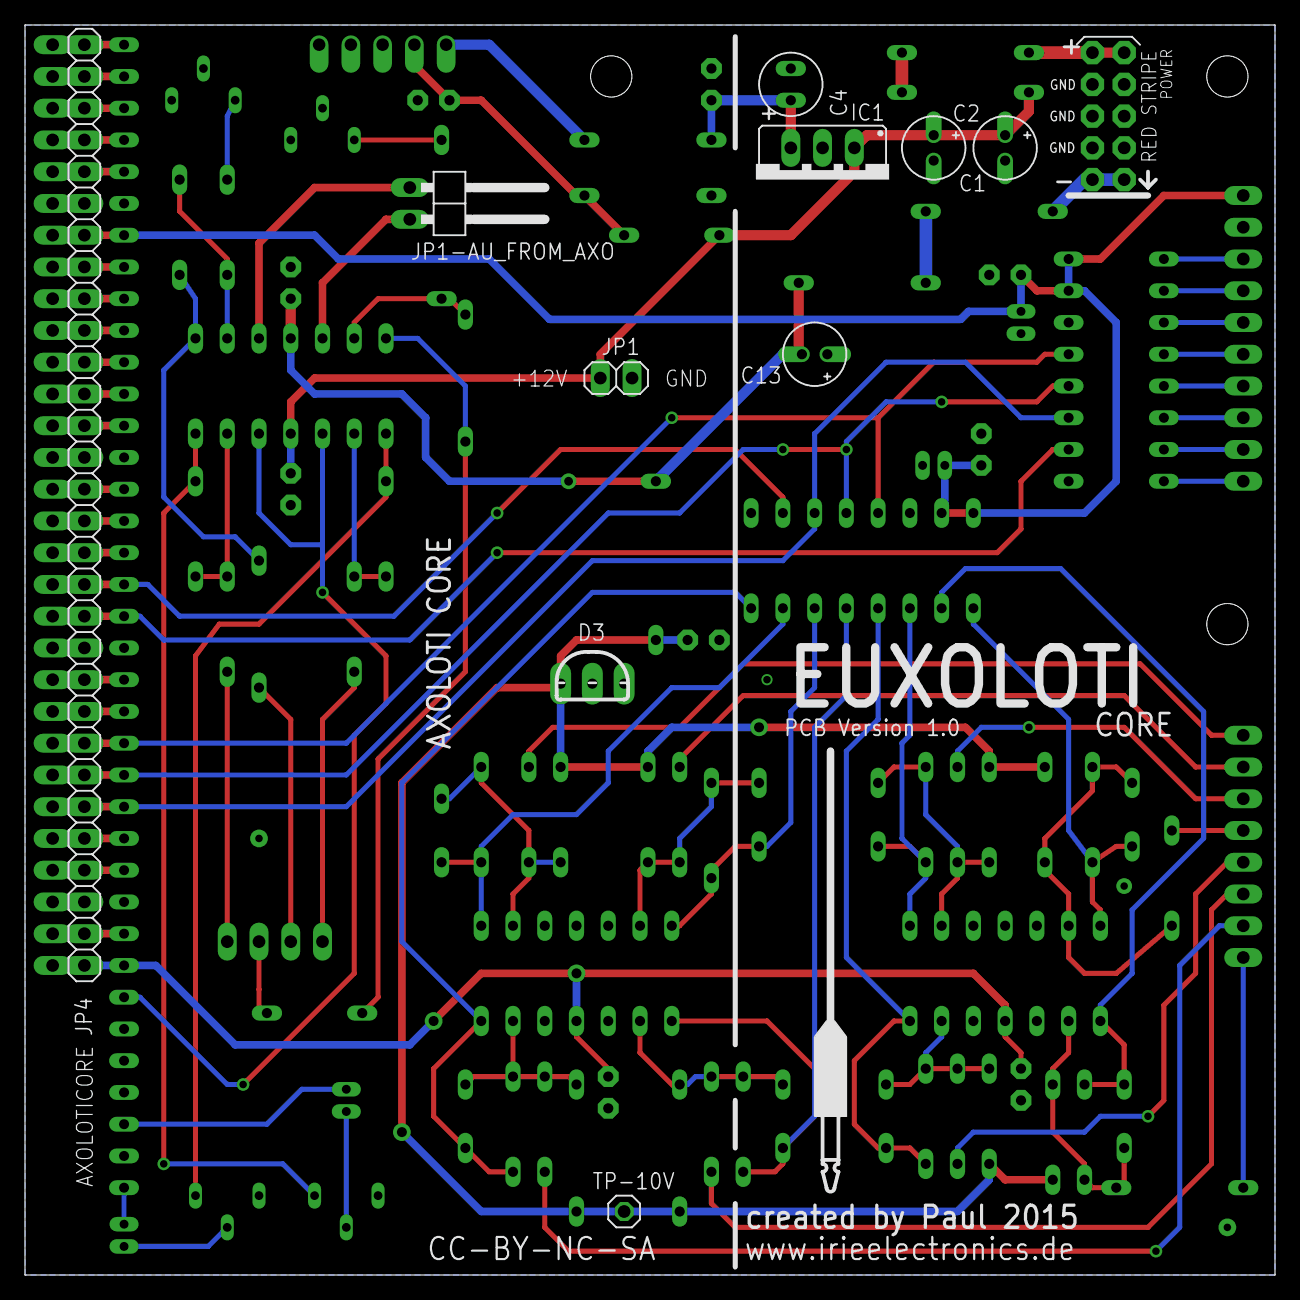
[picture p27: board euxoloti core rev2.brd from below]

Board: 4 copper layers, 100.0 x 100.0 mm, 89 parts (13 on the bottom side), 90 nets.

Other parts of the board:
U$1: KLINKENBILD

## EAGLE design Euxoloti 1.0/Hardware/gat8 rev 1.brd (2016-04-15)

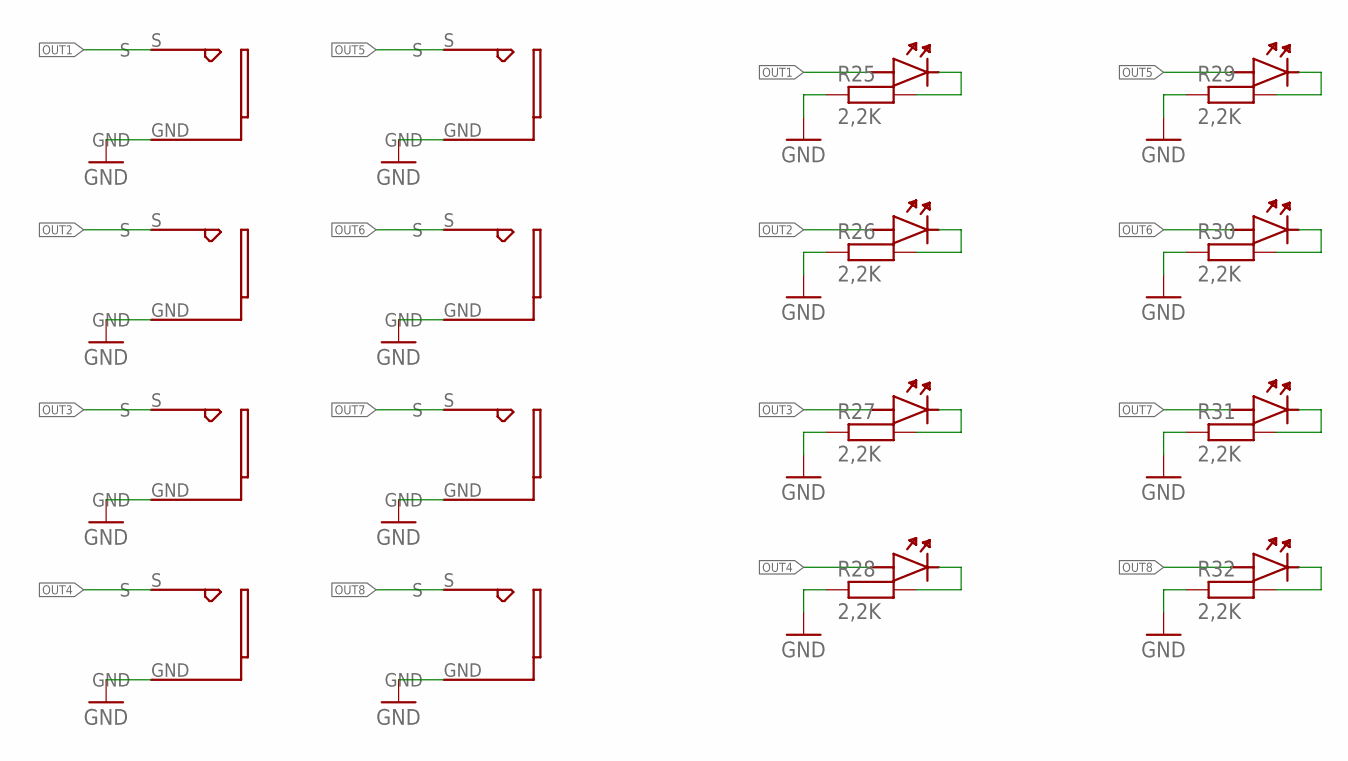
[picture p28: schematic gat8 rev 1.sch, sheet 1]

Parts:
LED8: LED
OUT1, OUT2, OUT3, OUT4, OUT5, OUT6, OUT7, OUT8: PJ302M
R25, R26, R27, R28, R29, R30, R31, R32: 2,2K; R1206
U$1, U$2, U$3, U$4, U$5, U$6, U$7: LED

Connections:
GND: OUT1.GND, OUT2.GND, OUT3.GND, OUT4.GND, OUT5.GND, OUT6.GND, OUT7.GND, OUT8.GND, R25.1, R26.1, R27.1, R28.1, R29.1, R30.1, R31.1, R32.1; also elsewhere on the board
unnamed: R26.2, U$2.GND
unnamed: R25.2, U$1.GND
unnamed: R27.2, U$3.GND
unnamed: R28.2, U$4.GND
unnamed: LED8.GND, R32.2
unnamed: R31.2, U$7.GND
unnamed: R30.2, U$6.GND
unnamed: R29.2, U$5.GND
OUT1: OUT1.S, U$1.S; also elsewhere on the board
OUT2: OUT2.S, U$2.S; also elsewhere on the board
OUT3: OUT3.S, U$3.S; also elsewhere on the board
OUT4: OUT4.S, U$4.S; also elsewhere on the board
OUT5: OUT5.S, U$5.S; also elsewhere on the board
OUT6: OUT6.S, U$6.S; also elsewhere on the board
OUT7: OUT7.S, U$7.S; also elsewhere on the board
OUT8: LED8.S, OUT8.S; also elsewhere on the board

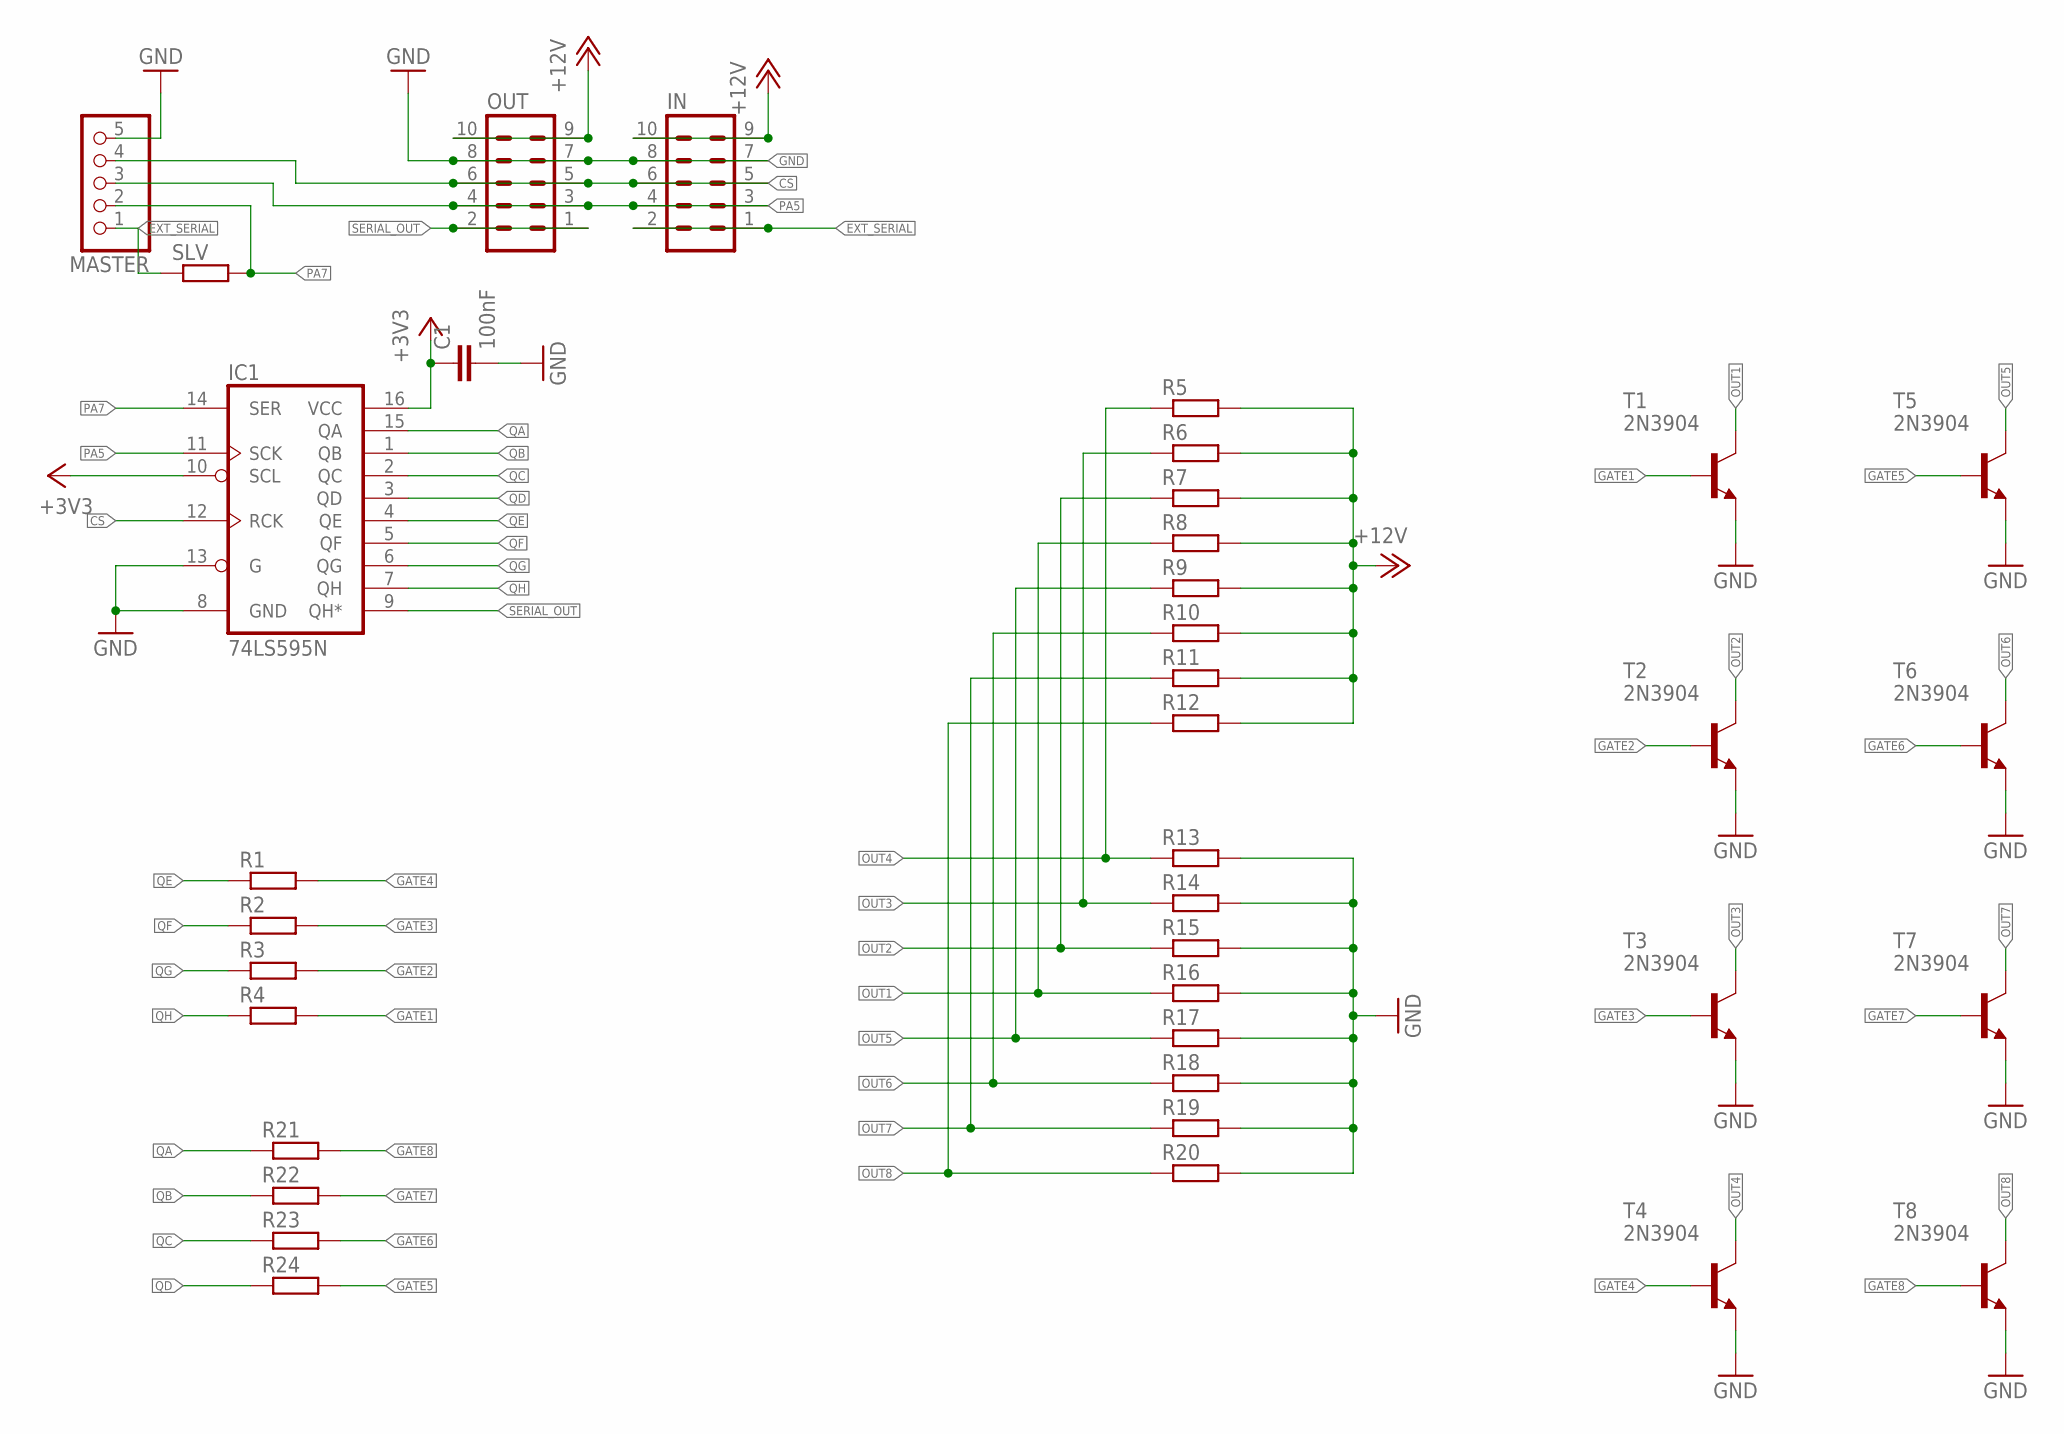
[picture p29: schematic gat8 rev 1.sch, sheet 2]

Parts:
C1: 100nF; C1206K
IC1: 74LS595N; DIL16
IN: ML10
MASTER: PINHD-1X5_2.54; 1X05
OUT: ML10
R1, R2, R3, R4, R5, R6, R7, R8, R9, R10, R11, R12, R13, R14, R15, R16, R17, R18, R19, R20, R21, R22, R23, R24: R-EU_R1206; R1206
SLV: R-EU_R0805; R0805
T1, T2, T3, T4, T5, T6, T7, T8: 2N3904; TO92

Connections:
+3V3: C1.1, IC1.10 (SCL), IC1.16 (VCC); also elsewhere on the board
+12V: IN.9, IN.10, OUT.9, OUT.10, R5.2, R6.2, R7.2, R8.2, R9.2, R10.2, R11.2, R12.2; also elsewhere on the board
CS: IC1.12 (RCK), IN.5, IN.6, MASTER.4, OUT.5, OUT.6
EXT_SERIAL: IN.1, IN.2, MASTER.1, SLV.1
GATE1: R4.2, T1.2 (B)
GATE2: R3.2, T2.2 (B)
GATE3: R2.2, T3.2 (B)
GATE4: R1.2, T4.2 (B)
GATE5: R24.2, T5.2 (B)
GATE6: R23.2, T6.2 (B)
GATE7: R22.2, T7.2 (B)
GATE8: R21.2, T8.2 (B)
GND: C1.2, IC1.8 (GND), IC1.13 (G), IN.7, IN.8, MASTER.5, OUT.7, OUT.8, R13.2, R14.2, R15.2, R16.2, R17.2, R18.2, R19.2, R20.2, T1.3 (E), T2.3 (E), T3.3 (E), T4.3 (E), T5.3 (E), T6.3 (E), T7.3 (E), T8.3 (E); also elsewhere on the board
OUT1: R8.1, R16.1, T1.1 (C); also elsewhere on the board
OUT2: R7.1, R15.1, T2.1 (C); also elsewhere on the board
OUT3: R6.1, R14.1, T3.1 (C); also elsewhere on the board
OUT4: R5.1, R13.1, T4.1 (C); also elsewhere on the board
OUT5: R9.1, R17.1, T5.1 (C); also elsewhere on the board
OUT6: R10.1, R18.1, T6.1 (C); also elsewhere on the board
OUT7: R11.1, R19.1, T7.1 (C); also elsewhere on the board
OUT8: R12.1, R20.1, T8.1 (C); also elsewhere on the board
PA5: IC1.11 (SCK), IN.3, IN.4, MASTER.3, OUT.3, OUT.4
PA7: IC1.14 (SER), MASTER.2, SLV.2
QA: IC1.15 (QA), R21.1
QB: IC1.1 (QB), R22.1
QC: IC1.2 (QC), R23.1
QD: IC1.3 (QD), R24.1
QE: IC1.4 (QE), R1.1
QF: IC1.5 (QF), R2.1
QG: IC1.6 (QG), R3.1
QH: IC1.7 (QH), R4.1
SERIAL_OUT: IC1.9 (QH*), OUT.1, OUT.2


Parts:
C2, C4, C5: 47uF; E2-5
C6: 100nF; C1206K
D1: 1N4001; DO41-10
IC2: LM117-3.3V; SOT223
L1: L-EU0207/10; 0207/10
POWER: EURO_POWER_HEADERFAT_PADS; EURO_PWR_HEADER_FAT
U$9: LABEL_COMPLETE; LABELCOMPLETE

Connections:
+3V3: C4.+, C6.1, IC2.3 (VOUT); also elsewhere on the board
+12V: C2.+, D1.C, L1.1; also elsewhere on the board
GND: C2.-, C4.-, C5.-, C6.2, IC2.2 (GND), POWER.3, POWER.4, POWER.5, POWER.6, POWER.7, POWER.8; also elsewhere on the board
unnamed: D1.A, POWER.9, POWER.10
VCC: C5.+, IC2.1 (VIN), L1.2



Board: 4 copper layers, 43.3 x 100.0 mm, 71 parts (44 on the bottom side), 42 nets.

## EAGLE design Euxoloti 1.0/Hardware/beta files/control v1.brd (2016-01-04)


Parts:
JP-POT: PINHD-1X10_2.54; 1X10
POT1, POT2, POT3, POT4, POT5, POT6, POT7, POT8: 10K; 9MM_SNAP-IN_POT

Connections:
+3V3: POT1.3 (E), POT2.3 (E), POT3.3 (E), POT4.3 (E), POT5.3 (E), POT6.3 (E), POT7.3 (E), POT8.3 (E); also elsewhere on the board
GND: JP-POT.2, POT1.1 (A), POT2.1 (A), POT3.1 (A), POT4.1 (A), POT5.1 (A), POT6.1 (A), POT7.1 (A), POT8.1 (A); also elsewhere on the board
POT1: JP-POT.4, POT1.2 (S)
POT2: JP-POT.3, POT2.2 (S)
POT3: JP-POT.5, POT3.2 (S)
POT4: JP-POT.6, POT4.2 (S)
POT5: JP-POT.8, POT5.2 (S)
POT6: JP-POT.10, POT6.2 (S)
POT7: JP-POT.9, POT7.2 (S)
POT8: JP-POT.7, POT8.2 (S)


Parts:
CV1, CV2, CV3, CV4, CV5, CV6, CV7, CV8: THONKICONNNEW; WQP-PJ301M-12_JACK
JP3-CV: PINHD-1X8; 1X08

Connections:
CV1: CV1.P$1_TIP, JP3-CV.1
CV2: CV2.P$1_TIP (TIP), JP3-CV.2
CV3: CV3.P$1_TIP, JP3-CV.3
CV4: CV4.P$1_TIP (TIP), JP3-CV.4
CV5: CV5.P$1_TIP, JP3-CV.5
CV6: CV6.P$1_TIP (TIP), JP3-CV.6
CV7: CV7.P$1_TIP, JP3-CV.7
CV8: CV8.P$1_TIP (TIP), JP3-CV.8
GND: CV2.P$3_SLEEVE (SLEEVE), CV4.P$3_SLEEVE (SLEEVE), CV6.P$3_SLEEVE (SLEEVE), CV8.P$3_SLEEVE (SLEEVE); also elsewhere on the board


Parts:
B1, B2, B3, B4: LP4OA1PBCTG; LP4OA1PBCT
R1, R3, R5, R7: 34,8R; 0207/7

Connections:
B1: B1.P2, B1.P5; also elsewhere on the board
B2: B2.P2, B2.P5; also elsewhere on the board
B3: B3.P2, B3.P5; also elsewhere on the board
B4: B4.P2, B4.P5; also elsewhere on the board
GND: B1.L2, B1.P3, B1.P6, B2.P3, B2.P6, B3.P3, B3.P6, B4.P3, B4.P6, R3.2, R5.2, R7.2; also elsewhere on the board
L1: R1.1; also elsewhere on the board
L2: B2.L1; also elsewhere on the board
L3: B3.L1; also elsewhere on the board
L4: B4.L1; also elsewhere on the board
unnamed: B2.L2, R3.1
unnamed: B3.L2, R5.1
unnamed: B1.L1, R1.2
unnamed: B4.L2, R7.1


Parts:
A-IN1, A-IN2: THONKICONNNEW; WQP-PJ301M-12_JACK
A-OUT1, A-OUT2: THONKICONNNEW; WQP-PJ301M-12_JACK
JP3-AUDIO: PINHD-1X4; 1X04

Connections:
AUDIO_IN1: A-IN1.P$1_TIP (TIP), A-IN2.P$2_SWITCH (SWITCH), JP3-AUDIO.1
AUDIO_IN2: A-IN2.P$1_TIP (TIP), JP3-AUDIO.4
AUDIO_OUT1: A-OUT1.P$1_TIP, JP3-AUDIO.2
AUDIO_OUT2: A-OUT2.P$1_TIP, JP3-AUDIO.3
GND: A-IN1.P$2_SWITCH (SWITCH), A-IN1.P$3_SLEEVE (SLEEVE), A-IN2.P$3_SLEEVE (SLEEVE); also elsewhere on the board


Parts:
G-IN1, G-IN2: THONKICONNNEW; WQP-PJ301M-12_JACK
R9, R10: 100K; 0207/7
R11, R12: 10K; 0207/7
T1, T2: 2N3904; TO92

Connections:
GATE1: R11.1, T1.1 (C); also elsewhere on the board
GATE2: R12.1, T2.1 (C); also elsewhere on the board
GND: G-IN2.P$2_SWITCH (SWITCH), G-IN2.P$3_SLEEVE (SLEEVE), T1.3 (E), T2.3 (E); also elsewhere on the board
unnamed: G-IN1.P$1_TIP, R9.1
unnamed: G-IN2.P$1_TIP (TIP), R10.1
unnamed: R9.2, T1.2 (B)
unnamed: R10.2, T2.2 (B)
VDD: R11.2, R12.2; also elsewhere on the board

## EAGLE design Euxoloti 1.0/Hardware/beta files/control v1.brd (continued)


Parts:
C1: 100n; C025-025X050
JP1: PINHD-1X30; 1X30
JP2, JP4, JP5, JP6, JP7, JP8: PINHD-1X1; 1X01

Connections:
+3V3: C1.2, JP1.24; also elsewhere on the board
B1: JP1.22; also elsewhere on the board
B2: JP1.20; also elsewhere on the board
B3: JP1.18; also elsewhere on the board
B4: JP1.14; also elsewhere on the board
GATE1: JP1.4; also elsewhere on the board
GATE2: JP1.5; also elsewhere on the board
GND: C1.1, JP1.3, JP1.11, JP1.17, JP1.25, JP2.1, JP4.1, JP5.1, JP6.1, JP7.1, JP8.1; also elsewhere on the board
L1: JP1.23; also elsewhere on the board
L2: JP1.21; also elsewhere on the board
L3: JP1.19; also elsewhere on the board
L4: JP1.15; also elsewhere on the board
VDD: JP1.1; also elsewhere on the board



Board: 4 copper layers, 100.0 x 100.0 mm, 47 parts (3 on the bottom side), 41 nets.

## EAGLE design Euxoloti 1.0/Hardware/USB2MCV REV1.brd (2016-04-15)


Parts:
C6, C7, C8, C9: 220pF; C1206K
C10, C11: 100nF; C1206K
IC2: TL074P; DIL14
OUT1, OUT2: PJ302M
R2, R3, R7: 100K; R1206
R5, R14: 220K; R1206
R6, R13: 100R; R1206
R9, R10: 33K; R1206
R11: 30K; R1206
R12: 120K; R1206
R15: 50K; RTRIM64Y

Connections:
+12V: C10.1, IC2.4 (V+); also elsewhere on the board
-12V: C11.2, IC2.11 (V-); also elsewhere on the board
GND: C6.2, C8.2, C10.2, C11.1, IC2.10 (+IN), OUT1.GND, OUT2.GND, R7.1; also elsewhere on the board
unnamed: C6.1, IC2.3 (+IN), R3.2
unnamed: C7.1, R2.2, R3.1
unnamed: IC2.13 (-IN), R5.1, R7.2
unnamed: IC2.14 (OUT), R5.2, R6.1
unnamed: C9.2, IC2.6 (-IN), IC2.7 (OUT), R11.1
unnamed: C8.1, IC2.5 (+IN), R10.2
unnamed: C9.1, R9.2, R10.1
unnamed: IC2.9 (-IN), R11.2, R12.1, R14.2
unnamed: IC2.8 (OUT), R12.2, R13.1
unnamed: R14.1, R15.1 (E)
unnamed: C7.2, IC2.1 (OUT), IC2.2 (-IN), IC2.12 (+IN)
OUT1: OUT1.S, R6.2
OUT2: OUT2.S, R13.2
OUTA: R2.1; also elsewhere on the board
OUTB: R9.1; also elsewhere on the board
VREF-10: R15.2 (S), R15.3 (A); also elsewhere on the board


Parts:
C14: 100nF; C1206K
CS: R-US_R0402; R0402
DAC: PINHD-1X3_2.54; 1X03
IC5: DAC8552; MSOP-8
JP-LINK: ML10

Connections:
+3V3: C14.2, IC5.1 (VDD); also elsewhere on the board
+12V: JP-LINK.9, JP-LINK.10; also elsewhere on the board
CS: CS.1, JP-LINK.5, JP-LINK.6
DIN: DAC.1, IC5.7 (DIN), JP-LINK.1, JP-LINK.2
GND: C14.1, IC5.8 (GND), JP-LINK.7, JP-LINK.8; also elsewhere on the board
OUTA: IC5.4 (OUTA); also elsewhere on the board
OUTB: IC5.3 (OUTB); also elsewhere on the board
SCLK: DAC.2, IC5.6 (SCLK), JP-LINK.3, JP-LINK.4
SYNC: CS.2, DAC.3, IC5.5 (SYNC)
VREF2.5: IC5.2 (VREF); also elsewhere on the board


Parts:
C1, C2: 22uF; E2-5
C4, C5, C12, C16: 100nF; C1206K
D1, D2: 1N4001; DO41-10
D4: LM4040-2.5; TO-92
D5: LM4040-10; TO-92
IC1: 7803; 78LXX
IC3: 7805; 78LXX
L1, L2: L-EU0207/10; 0207/10
POWER: EURO_POWER_HEADERFAT_PADS; EURO_PWR_HEADER_FAT
R1: 3,3K; R1206
R16: 270R; R1206
U$1: LABEL_USB2MCV; LABEL_USB2DAC

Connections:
+3V3: C4.1, IC1.OUT, R1.1; also elsewhere on the board
+5V: C16.1, IC3.OUT; also elsewhere on the board
+12V: C1.+, IC1.IN, IC3.IN, L1.2; also elsewhere on the board
-12V: C2.-, L2.2, R16.1; also elsewhere on the board
GND: C1.-, C2.+, C4.2, C5.2, C12.2, C16.2, D4.A, D5.C, IC1.GND, IC3.GND, POWER.3, POWER.4, POWER.5, POWER.6, POWER.7, POWER.8; also elsewhere on the board
unnamed: D2.C, POWER.1, POWER.2
unnamed: D1.A, POWER.9, POWER.10
unnamed: D2.A, L2.1
unnamed: D1.C, L1.1
VREF2.5: C5.1, D4.C, R1.2; also elsewhere on the board
VREF-10: C12.1, D5.A, R16.2; also elsewhere on the board


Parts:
C13: 100nF; C1206K
D3: 1N4148; DO35-7
IC4: 6N137; DIL08
JP1: PINHD-1X4_2.54; 1X04
LED1: LED1206; LED-1206
M1: MIDI-IN; CP-2350
M2: MIDI-OUT; CP-2350
MIDI: PINHD-1X3_2.54; 1X03
R4, R17, R18, R19: 220R; R1206@1
SLED: STATUS_LED; STAUS-LED(DIP)
USB-A: USB-A_JACK; USB-A
USB-B: USB-B; USB-B-PTH

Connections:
+5V: C13.1, IC4.8 (VCC), R17.2; also elsewhere on the board
D+: JP1.3, USB-A.3 (D+), USB-B.D+
D-: JP1.2, USB-A.2 (D-), USB-B.D-
GND: C13.2, IC4.5 (GND), M2.2, MIDI.1; also elsewhere on the board
unnamed: LED1.A, R4.1, SLED.A
unnamed: D3.C, IC4.2 (A), R19.2
unnamed: M2.5, R18.2
unnamed: JP1.1, R4.2, USB-A.1 (VBUS), USB-B.VBUS
unnamed: M2.4, R17.1
unnamed: M1.4, R19.1
unnamed: D3.A, IC4.3 (C), M1.5
RX: IC4.6 (VO), MIDI.3
TX: MIDI.2, R18.1
USB_GND: JP1.4, LED1.C, SLED.K, USB-A.4 (GND), USB-B.GND



Board: 4 copper layers, 55.0 x 99.9 mm, 60 parts (4 on the bottom side), 42 nets.

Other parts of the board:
U$2: WINKEL; WINKEL90°

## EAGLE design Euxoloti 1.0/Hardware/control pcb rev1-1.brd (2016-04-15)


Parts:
JP-POT1: PINHD-1X10_2.54; 1X10
POT1, POT2, POT3, POT4, POT5, POT6, POT7, POT8: 10K; 9MM_SNAP-IN_POT

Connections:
FVDD: JP-POT1.10, POT1.3 (E), POT2.3 (E), POT3.3 (E), POT4.3 (E), POT5.3 (E), POT6.3 (E), POT7.3 (E), POT8.3 (E)
GNDPOT: JP-POT1.9, POT1.1 (A), POT2.1 (A), POT3.1 (A), POT4.1 (A), POT5.1 (A), POT6.1 (A), POT7.1 (A), POT8.1 (A)
POT1: JP-POT1.1, POT1.2 (S)
POT2: JP-POT1.2, POT2.2 (S)
POT3: JP-POT1.3, POT3.2 (S)
POT4: JP-POT1.4, POT4.2 (S)
POT5: JP-POT1.8, POT5.2 (S)
POT6: JP-POT1.7, POT6.2 (S)
POT7: JP-POT1.6, POT7.2 (S)
POT8: JP-POT1.5, POT8.2 (S)


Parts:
CV1, CV2, CV3, CV4, CV5, CV6, CV7, CV8: THONKICONNNEW; WQP-PJ301M-12_JACK
JP-CV: PINHD-1X9_2.54; 1X09

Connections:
CV1: CV5.P$1_TIP (TIP), JP-CV.1
CV2: CV1.P$1_TIP (TIP), JP-CV.2
CV3: CV6.P$1_TIP (TIP), JP-CV.3
CV4: CV2.P$1_TIP (TIP), JP-CV.4
CV5: CV7.P$1_TIP (TIP), JP-CV.5
CV6: CV3.P$1_TIP (TIP), JP-CV.6
CV7: CV8.P$1_TIP (TIP), JP-CV.7
CV8: CV4.P$1_TIP (TIP), JP-CV.8
GNDCV: CV1.P$3_SLEEVE (SLEEVE), CV2.P$3_SLEEVE (SLEEVE), CV3.P$3_SLEEVE (SLEEVE), CV4.P$3_SLEEVE (SLEEVE), CV5.P$3_SLEEVE (SLEEVE), CV6.P$3_SLEEVE (SLEEVE), CV7.P$3_SLEEVE (SLEEVE), CV8.P$3_SLEEVE (SLEEVE), JP-CV.9; also elsewhere on the board


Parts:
B1, B2, B3, B4: LP4OA1PBCTG/D6; LP4OA1PBCT
R1, R3, R5, R7: 100R; 0207/7

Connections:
AXOGND: B1.L2, B1.P3, B1.P6, B2.P3, B2.P6, B3.P3, B3.P6, B4.P3, B4.P6, R3.2, R5.2, R7.2; also elsewhere on the board
B1: B1.P2, B1.P5; also elsewhere on the board
B2: B2.P2, B2.P5; also elsewhere on the board
B3: B3.P2, B3.P5; also elsewhere on the board
B4: B4.P2, B4.P5; also elsewhere on the board
L1: R1.1; also elsewhere on the board
L2: B2.L1; also elsewhere on the board
L3: B3.L1; also elsewhere on the board
L4: B4.L1; also elsewhere on the board
unnamed: B2.L2, R3.1
unnamed: B3.L2, R5.1
unnamed: B1.L1, R1.2
unnamed: B4.L2, R7.1


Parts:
A-IN1, A-IN2: THONKICONNNEW; WQP-PJ301M-12_JACK
A-OUT1, A-OUT2: THONKICONNNEW; WQP-PJ301M-12_JACK
JP-AUDIO: PINHD-2X4_2.54; 2X04

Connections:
AUDIO_IN1: A-IN1.P$1_TIP (TIP), A-IN2.P$2_SWITCH (SWITCH), JP-AUDIO.8
AUDIO_IN2: A-IN2.P$1_TIP (TIP), JP-AUDIO.2
AUDIO_OUT1: A-OUT1.P$1_TIP (TIP), JP-AUDIO.5, JP-AUDIO.6
AUDIO_OUT2: A-OUT2.P$1_TIP (TIP), JP-AUDIO.3, JP-AUDIO.4
GNDB: A-IN1.P$2_SWITCH (SWITCH), A-IN1.P$3_SLEEVE (SLEEVE), A-IN2.P$3_SLEEVE (SLEEVE), A-OUT1.P$3_SLEEVE (SLEEVE), A-OUT2.P$3_SLEEVE (SLEEVE), JP-AUDIO.1, JP-AUDIO.7


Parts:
G-IN1, G-IN2: THONKICONNNEW; WQP-PJ301M-12_JACK
R2, R4: 100K; 0207/7
R11, R12: 10K; 0207/7
T1, T2: 2N3904; TO92

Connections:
GATE1: R11.1, T1.1 (C); also elsewhere on the board
GATE2: R12.1, T2.1 (C); also elsewhere on the board
GNDCV: G-IN1.P$2_SWITCH (SWITCH), G-IN1.P$3_SLEEVE (SLEEVE), G-IN2.P$2_SWITCH (SWITCH), G-IN2.P$3_SLEEVE (SLEEVE), T1.3 (E), T2.3 (E); also elsewhere on the board
unnamed: G-IN2.P$1_TIP (TIP), R2.2
unnamed: G-IN1.P$1_TIP (TIP), R4.2
unnamed: R2.1, T1.2 (B)
unnamed: R4.1, T2.2 (B)
VDD: R11.2, R12.2; also elsewhere on the board


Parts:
JP1: PINHD-1X30; 1X30

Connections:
AXOGND: JP1.3, JP1.11, JP1.17, JP1.25; also elsewhere on the board
B1: JP1.29; also elsewhere on the board
B2: JP1.28; also elsewhere on the board
B3: JP1.23; also elsewhere on the board
B4: JP1.22; also elsewhere on the board
GATE1: JP1.21; also elsewhere on the board
GATE2: JP1.20; also elsewhere on the board
L1: JP1.15; also elsewhere on the board
L2: JP1.14; also elsewhere on the board
L3: JP1.4; also elsewhere on the board
L4: JP1.5; also elsewhere on the board
VDD: JP1.2; also elsewhere on the board

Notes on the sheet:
SPI
UART
I2C

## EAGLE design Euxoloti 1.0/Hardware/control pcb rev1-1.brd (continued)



Board: 4 copper layers, 100.0 x 107.6 mm, 40 parts (4 on the bottom side), 44 nets.

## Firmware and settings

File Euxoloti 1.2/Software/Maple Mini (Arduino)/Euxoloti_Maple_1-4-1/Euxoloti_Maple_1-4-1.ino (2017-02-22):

/*  Arduino - Axoloti communcation and I/O expanding for EUXOLOTI 1.2
 *  created by Paul 2016 - www.irieelectronics.de
 *  licence: BSD
 *
 *  SV: 1.4.1
 *
 *  Hardware Setup UART:
 *  Maple Mini (UART)
 *  RX3 = D0 (PB11)
 *  TX3 = D1 (PB10)
 *
 *  Axoloti (UART)
 *  RX = PA3
 *  TX = PA2
 *
 *  TX and RX need 10K pullup resitor (3,3V) to stabilize serial port while axoloti resets or load new patches.
 *
 *  changelog:
 *  - added Debug options
 *  - send CC by midiReset message
 */


#include <MIDI.h>

// Debug option
#define serialDebug Serial // select Serialport for debugging 
#define debug 0
#define adcDebug 0

struct euxoSettings : public midi::DefaultSettings
{
  static const bool UseRunningStatus = false; // Messes with my old equipment!
  static const bool HandleNullVelocityNoteOnAsNoteOff = true;
  static const bool Use1ByteParsing = true;
  static const long BaudRate = 115200; // should be equal to axo settings
  static const unsigned SysExMaxSize = 128; // not implemented in axo object
};

MIDI_CREATE_CUSTOM_INSTANCE(HardwareSerial, Serial3, euxo, euxoSettings);

#define midiCh_In 1     // MIDI IN channel
#define midiCh_Out 1    // MIDI OUT channel

// maple mini pin outs
const uint8_t button[] = {22, 21, 20, 19};
const uint8_t led[] = {25, 16, 26, 11};
const uint8_t pot[] = {10, 9, 8, 7, 4, 3, 5, 6};

// button state section
uint8_t buttonState[4];
uint8_t lastButtonState[4] = {HIGH, HIGH, HIGH, HIGH};  // default state

// for debouncing
long buttonLastDebounceTime[] = {0, 0, 0, 0}; // the last time the output pin was toggled
long buttonDebounceDelay = 50; // the debounce time; increase if the output flickers
uint8_t buttonReading[4];

// adc section
uint32_t adcValue[] = {0, 0, 0, 0, 0, 0, 0, 0};
long adcLastValue[] = {0, 0, 0, 0, 0, 0, 0, 0};
bool adcCheck = false;  // for callback routine. not used at the moment.
unsigned long oldMillis[] =  {0, 0, 0, 0, 0, 0, 0, 0};
long adcLastDebounceTime[] = {0, 0, 0, 0, 0, 0, 0, 0}; // the last time the output pin has been changed
long adcDebounceDelay = 100; // the debounce time; increase if the output flickers

// average section
uint8_t adcTreshhold = 5;
uint8_t maxCount = 5;       // max. depends on adcbuf[]
uint8_t adcBuf[10];         // adc read buffer
uint32_t adcTempValue;  // temporary storage
bool ioStatus = false;
bool midiRequest = 0;

void midiReset () {
  for (uint8_t b = 0; b < 4; b++) {
    analogWrite(led[b], 65535);   // scale midi max 7bit to 16bit pwm
    //delay(50);
  }
  for (uint8_t pR = 0; pR < 8; pR++) {
    digitalWrite(PB1, LOW);
    delay(10);


    adcLastValue[pR] = analogRead(pot[pR]);
    euxo.sendControlChange(pR + 1, (adcLastValue[pR] >> 5), midiCh_Out);
    digitalWrite(PB1, HIGH);
  }

  for (uint8_t c = 0; c < 4; c++) {
    analogWrite(led[c], 0);   // scale midi max 7bit to 16bit pwm
  }
  if (debug != 0) {
    serialDebug.println("midi reset");
  }
}

void ccIn (byte channel, byte number, byte value) {
  if (number < 4) {                         // ignore any Note which is higher then 4 (0-3 correspond to LED pins)
    analogWrite(led[number], value << 9);   // scale midi max 7bit to 16bit pwm
  }                                         // and use value to control each LED by PWM modulation.
  else if (number == 5 && channel == 1) {
    adcTreshhold = value;
  }

  if (debug != 0 && adcDebug != 0) {
    serialDebug.println("CC received");
  }
}

void handleNoteOn (byte channel, byte note, byte value) {   //not used yet
  if (debug != 0) {
    serialDebug.println("note in received");
  }
}

void setup() {
  pinMode(PB1, OUTPUT);
  //digitalWrite(PB1, HIGH);
  if (debug != 0) {
    serialDebug.begin(115200);
    delay(10);
    serialDebug.println("debug enabled");
  }

  // pinMode(PB1, OUTPUT);                // maple mini onboard LED

  for (uint8_t i = 0; i < 4; i++) {           // setup pins for LED, BUTTON and GATE inputs.
    pinMode(button[i], INPUT);
    pinMode(led[i], PWM);
  }
  for (uint8_t a = 0; a < 4; a++) {
    analogWrite(led[a], 0);   // scale midi max 7bit to 16bit pwm

  }

  euxo.setHandleControlChange(ccIn);      // midi handle for Control Change messages = leds
  euxo.setHandleNoteOn(handleNoteOn);     // midi handle for Note On. Not used but usefull for callback tasks.
  euxo.setHandleSystemReset(midiReset);   // not used at the moment

  euxo.begin(midiCh_In);                  // start MIDI
  euxo.turnThruOff();                     // turn MIDI through off
  digitalWrite(PB1, HIGH);

  for (uint8_t b = 0; b < 4; b++) {
    analogWrite(led[b], 65535);   // scale midi max 7bit to 16bit pwm
    delay(50);
  }
  for (uint8_t c = 0; c < 4; c++) {
    analogWrite(led[c], 0);   // scale midi max 7bit to 16bit pwm
    delay(50);
  }
  delay(10);
}


void loop() {
  euxo.read();                                        // check if there is any incoming midi message
  // BUTTON SECTION

  for (uint8_t x = 0; x < 4; x++) {                       // go through every pin
    buttonReading[x] = digitalRead(button[x]);        // read current pin state

    if (buttonReading[x] != lastButtonState[x]) {     // if the button state has changed
      buttonLastDebounceTime[x] = millis();           // take a timestamp
    }
    if ((millis() - buttonLastDebounceTime[x]) > buttonDebounceDelay) {   // check if the state has changed within a pre selected time
      if (buttonReading[x] != buttonState[x]) {
        buttonState[x] = buttonReading[x];
        if (buttonState[x] == HIGH) {
          euxo.sendNoteOff(x, 0, midiCh_Out);        // send Note On message
          //analogWrite(led[x], 0);   // scale midi max 7bit to 16bit pwm
        }                                             // x=Note Number
        else if (buttonState[x] == LOW) {
          euxo.sendNoteOn(x, 127, midiCh_Out);         // send Note Off message
          //analogWrite(led[x], 127 << 9);   // scale midi max 7bit to 16bit pwm
        }
      }
    }
    lastButtonState[x] = buttonReading[x];            // store button State for next turn
  }

  for (uint8_t p = 0; p < 8; p++) {

    if ((abs(millis() - adcLastDebounceTime[p]) > adcDebounceDelay)) {


      uint16_t potState = analogRead(pot[p]);

      adcLastDebounceTime[p] = millis();

      if (abs(potState - adcLastValue[p]) >= adcTreshhold) {
        adcLastValue[p] = potState;
        euxo.sendControlChange(p + 1, (potState >> 5), midiCh_Out);
      }
    }
  }
}

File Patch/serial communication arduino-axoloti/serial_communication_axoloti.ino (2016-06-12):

/*  uart communication between arduino and axoloti core (v.1.0)
 *  by Paul 2016
 *  Serial Port connection:
 *  arduino RX -> axoloti core TX(PA2)
 *  arduino TX -> axoloti core RX(PA3)
 *  
 *  this example needs two serial ports at your arduino to work. 
 *  Please edit "Serial3." to "Serial." to run with only one serial port.
 */


uint8_t rxbuf[4];                 // for "l/" messages
String newTextmessage = "";       // string for incoming message
boolean messageComplete = false;  // state of completed string
bool message = false;             // state to dis-/enable string
int count = 0;                    // number of received strings.
int countMax = 20;                // max. number of counts

void setup() {
  Serial.begin(115200);           // initialize serial port
  Serial3.begin(115200);          // initialize 3.serial port. check your max. serial ports at your arduino. 
  newTextmessage.reserve(200);    // max. string size
  delay(5);
}

void loop() {
  
 if (Serial3.available()) {
    if (message == false) {                                         // check if no string is actually received.
      uint8_t messageDeclaration = Serial3.read();                  // read first byte of Serial3 buffer.
      uint8_t messageStart = Serial3.read();                        // read secound byte of Serial3 buffer.
      if (messageDeclaration == 'l' && messageStart == '/') {       // "l/" to receive four int to control e.g. pwm of leds
        ledMessage();                                            
      }
      else if (messageDeclaration == 'x' && messageStart == '/') {  // "x/" to flag an incoming string 
        message = true;
      }
    }
    else if(message == true) {            // string routine
      textMessage();                      // go to string analysing part
      if (messageComplete) {              // string is completed
        Serial.println(newTextmessage);   // send received string to Serial (arduino ide serial monitor)
        newTextmessage = "";              // reset string
        messageComplete = false;          // restart string receiving
        message = false;                  // disable string receiving
      }
    }
  }
}


void ledMessage() {             // after "l/", three values are send. whole message schould look like this: "l/value1 value2 value3 value4"
  rxbuf[0] = Serial3.read();    // 1.value (max.one byte 0-255)
  rxbuf[1] = Serial3.read();    // 2.value (max.one byte 0-255)
  rxbuf[2] = Serial3.read();    // 3.value (max.one byte 0-255)
  rxbuf[3] = Serial3.read();    // 4.value (max.one byte 0-255)
                                // print out the received values to Serial (arduino ide serial monitor)
  Serial.print(rxbuf[0]);
  Serial.print(" , ");
  Serial.print(rxbuf[1]);
  Serial.print(" , ");
  Serial.print(rxbuf[2]);
  Serial.print(" , ");
  Serial.println(rxbuf[3]);
}

void textMessage() {
  if (Serial3.available()>0) {
    char singleLetter = Serial3.read();     // receive characters by Serial3
    
    if (singleLetter == ';') {              // ";" at the end of a message flags end of message.
      if (count > countMax) {               // check count number
        count = 0;                          // reset count
        Serial3.write(count);             // send counts of string complete action to axoloti (example for callback)
      }
      count++;                              // count upwards same as  "count = count + 1;"
      messageComplete = true;               // stop character receiving loop
    }
    else {
      newTextmessage += singleLetter;       // add new character to already existing string elements
    }
  }
}

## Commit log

2015-12-31 eagle files
    [control v1.brd, control v1.sch, core v1.brd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]
2015-12-31 core schematic
2016-01-01 BOM PCB VERSION 1.00
2016-01-04 correct values
    [control v1.brd, control v1.sch, core v1.brd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]
2016-01-20 update REV 2
    [euxoloti core rev2.brd, euxoloti core rev2.sch]
2016-01-20 schematic pdf rev2
2016-02-27 calibration file
2016-03-02 TEST DAC8552 16bit SPI
2016-03-05 axoloti encoder patch
2016-03-06 LED DOT MATRIX (SPI & MAX7219)
2016-03-17 Update mpr121 i2c test.axp
2016-09-23 euxoloti 1.2 update
    [PCB PANEL Control V1.brd, PCB PANEL GAT8 V1.brd, PCB PANEL USB2MCV V1.brd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]
2016-10-06 Euxoloti 1.2/Axoloti audio calibration
2016-10-29 BOMs update
    [control 1-2 bom.xlsx, core 1-2 bom.xlsx, core 1-2.xlsx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]
2016-10-29 update part numbers
    [core 1-2.xlsx]
2017-02-12 updated script file (check new object "button_pot_led")

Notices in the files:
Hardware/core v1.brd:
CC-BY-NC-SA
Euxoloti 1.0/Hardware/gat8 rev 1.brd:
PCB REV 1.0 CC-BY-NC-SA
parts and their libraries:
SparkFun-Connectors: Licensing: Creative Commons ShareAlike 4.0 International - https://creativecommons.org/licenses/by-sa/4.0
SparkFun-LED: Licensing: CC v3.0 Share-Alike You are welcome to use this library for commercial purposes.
